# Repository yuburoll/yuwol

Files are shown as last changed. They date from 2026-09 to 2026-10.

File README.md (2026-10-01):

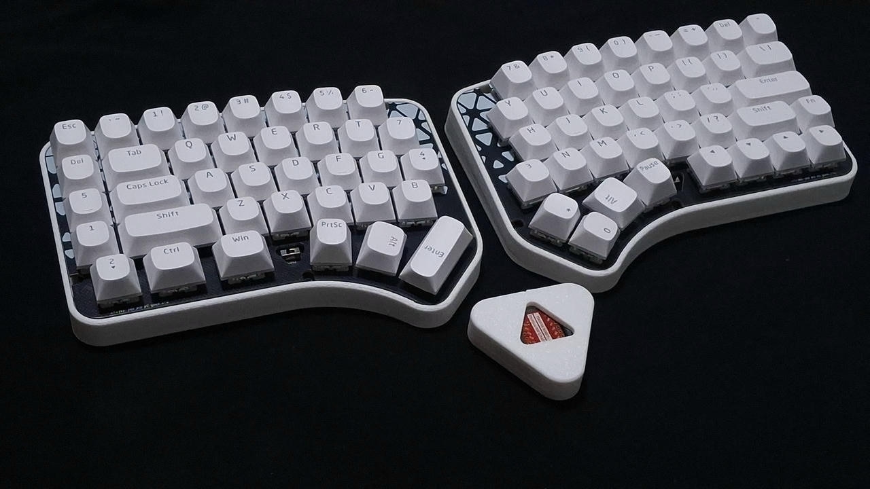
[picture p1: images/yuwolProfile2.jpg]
yuwol


# yuwol
row staggered 60% hotswappable keyboard with reversible PCB, little ergo boost of [ilwol](https://github.com/yuburoll/ilwol)

The name yuwol is June in Korean.

This keyboard has additional Y/H/B keys which positioned between keyboards, and auxilary row at left outside. You may put the keycaps from numpad.

This keyboard has hotswap-only PCB.

yuwol can change layout to followings:

- Split left shift, to ISO shaped one.(2.25u to 1.25u/1u)

- Split right shift, to HHKB inspired shape.(2.75u to 1.75u/1u)

- Split outside thumb keys(2u to 1u/1u)

- Split backspace(2u to 1u/1u)

- Can use stepped caps lock

## Preparation

common:

- 2x yuwol PCB Boards, provided from the repo

- 1x printed case sets, 2 parts total, provided from the repo

- 1x 1.5-1.6T keyboard plate sets, 2 parts total, provided from the repo

- 80x diodes, normally 1N4148

- 84x Kailh hotswap sockets (or compatibles)

- 2x 4x4x1.5mm surface mount tact switches (optional, for dev boards without reset button)

- 1-6x PCB Mounted 2u Keyboard Stabilizers, normally 6

- 73-78x MX Keyswitches, normally 73

- 8x 10mm bumpon stickers

- A set of Keycaps, Full-size layout, ANSI preferred.

for wired build:

- 2x pro micro form factor dev board

- 2x USB-C 6 pin jack, top mount

- 1x USB-C data cable

- 10x M2x6 screws / or M2x3x3 heat inserts and M2x6 bolts

for wireless build:

- 2x pro micro form factor dev board, with wireless chipset

- 2x 523450 battery, with molex picoblade 1.25mm pitch male, 2pin

- 2x molex picoblade 1.25mm pitch female, 2pin

- 2x SS-12D00 switches

- 2x battery cover, provided from the repo

- 14x M2x6 screws / or M2x3x3 heat inserts and M2x6 bolts

dongle:

- 1x pro micro form factor dev board, with wireless chipset

- 1x printed dongle case sets, 2 parts total, provided from the repo

- 2x M2x6 screws / or M2x3x3 heat inserts and M2x6 bolts

- 3x 10mm bumpon stickers

## Differences between case variations

- Screw: 1.5 pi mounting holes for screws

- Insert: 3 pi mounting holes for heat inserts

## Build Guides and Miscellaneous

[yuwol Build Guide](docs/buildGuide.md)

there's some notices before the build:

- You may solder all hotswaps before soldering the dev board.

- Assemble dev board with 2.5mm height pin headers on back side, assume that components side are faced up.

- Jump a jumper when it is left hand board.

[Additional Tenting Stand](https://github.com/yuburoll/yubuGadgets/tree/main/phalilwolTentingStand)

## Licenses

all codes follow MIT license.

all designs and the hardware board follow CC BY-SA 4.0 license.

Markdown documents and photos in docs/images folder are copyrighted, all rights reserved. You can use it for [fair use](https://www.copyright.gov/fair-use/).

If you want to make a commercial product, it would be appreciated if you sponsor some bucks for me.

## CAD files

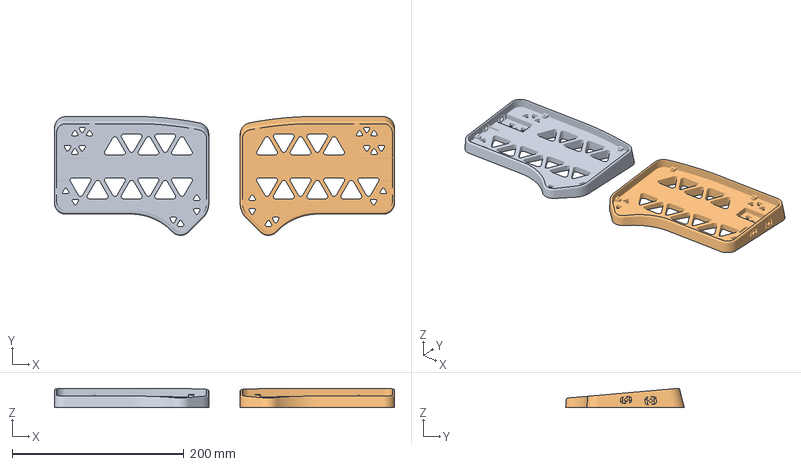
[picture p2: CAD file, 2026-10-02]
case/3mf/yuwolWiredInsert.3mf
395.5 x 138.2 x 22.5 mm
yuwolCaseWiredInsertBridgedL.stl
yuwolCaseWiredInsertBridgedR.stl

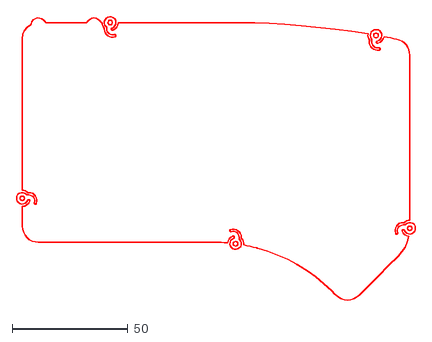
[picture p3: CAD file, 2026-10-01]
case/dxf/yuwolPCB.dxf
172.9 x 123.3

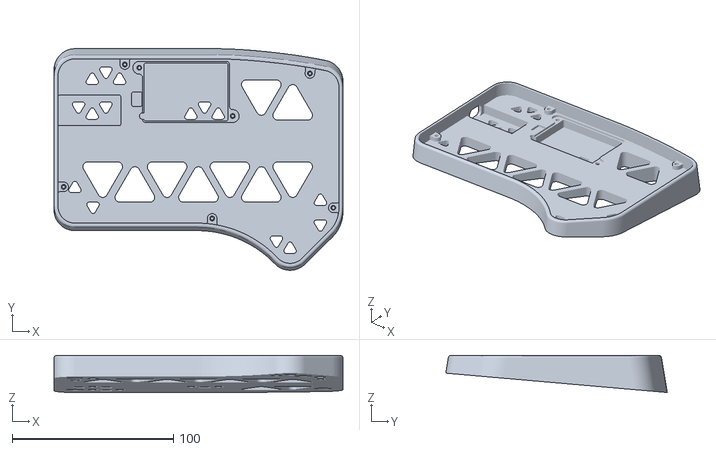
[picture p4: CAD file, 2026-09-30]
case/stl/insert/yuwolCaseWirelessInsertL.stl
179.5 x 137.6 x 23.0

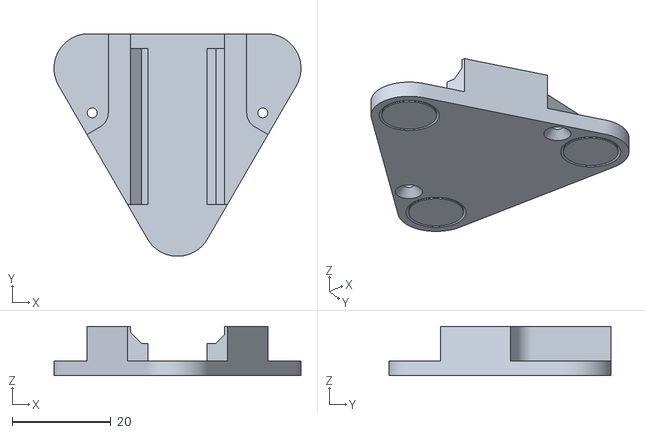
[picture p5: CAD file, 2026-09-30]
case/stl/yuwolDongleBottomBridged.stl
49.9 x 45.0 x 10.0

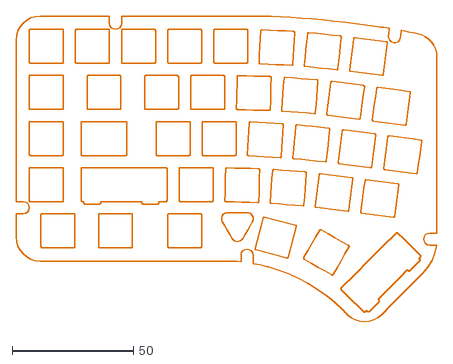
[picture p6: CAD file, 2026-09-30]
housing/dxf/yuwolPlateLeft.dxf
173.5 x 127.0

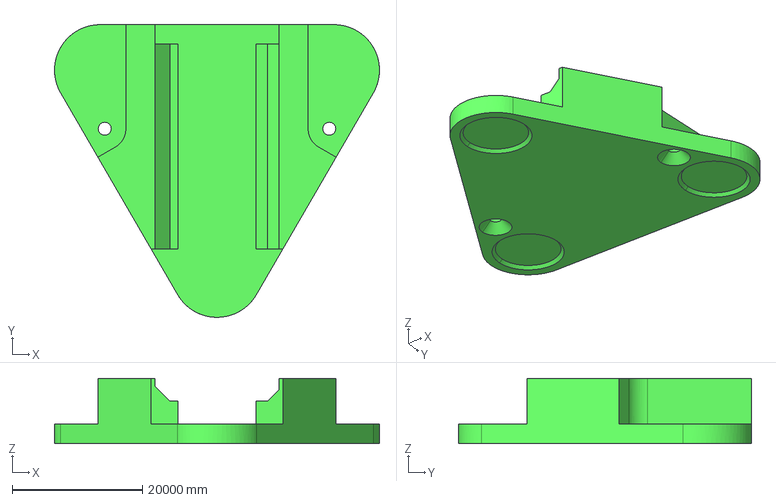
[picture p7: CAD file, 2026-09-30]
housing/step/yuwolDongleBottom.stp
49944.0 x 44986.3 x 10000.0 mm

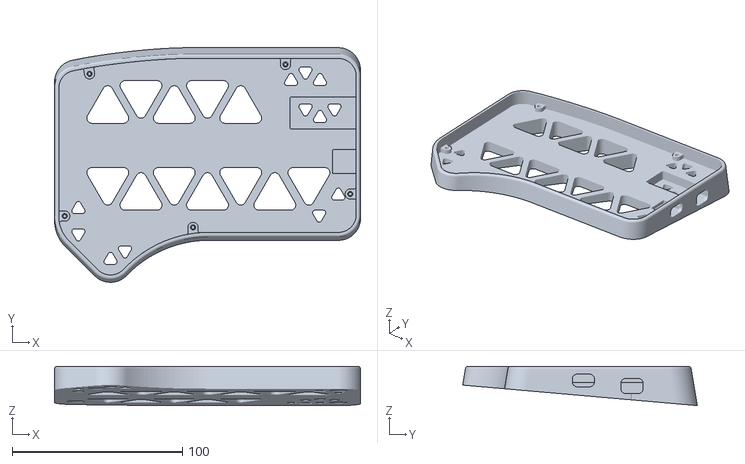
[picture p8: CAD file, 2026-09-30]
housing/stl/insert/yuwolCaseWiredInsertR.stl
179.5 x 137.6 x 23.0

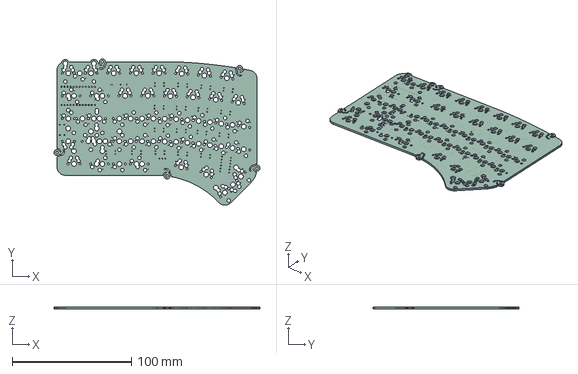
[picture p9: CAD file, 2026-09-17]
kicad/yuwolPCB.step
172.5 x 122.5 x 1.51 mm

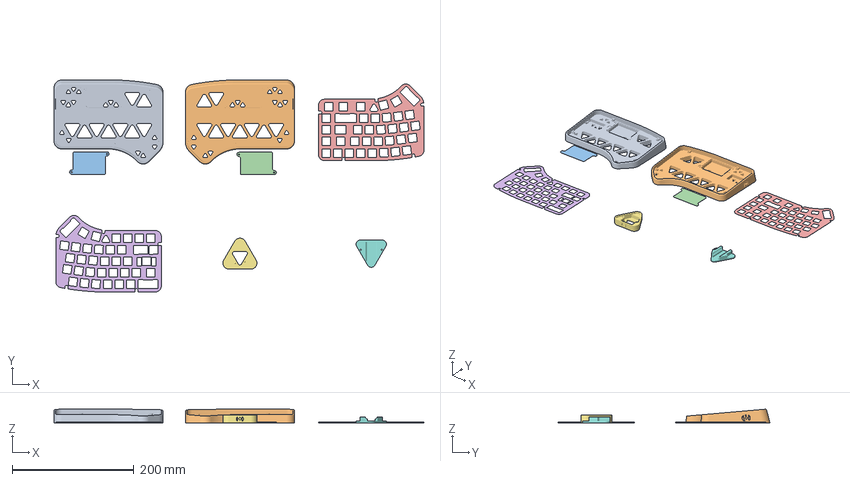
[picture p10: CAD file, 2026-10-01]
housing/3mf/yuwolWirelessInsert.3mf
608.5 x 348.5 x 22.5 mm
yuwolCaseWirelessInsertBridgedL.stl
yuwolCaseWirelessInsertBridgedR.stl
yuwolCaseWirelessBatteryCoverL.stl
yuwolCaseWirelessBatteryCoverR.stl
yuwolPlateL.stl
yuwolPlateR.stl
yuwolDongleTopInsertBridged.stl
yuwolDongleBottomBridged.stl

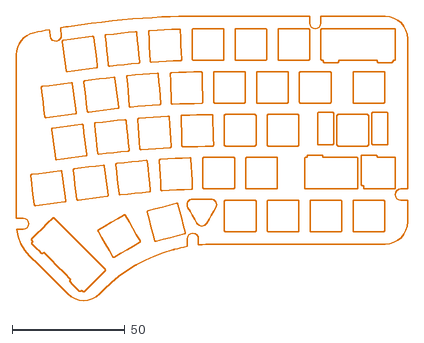
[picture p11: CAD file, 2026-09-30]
housing/dxf/yuwolPlateRight.dxf
173.5 x 127.0

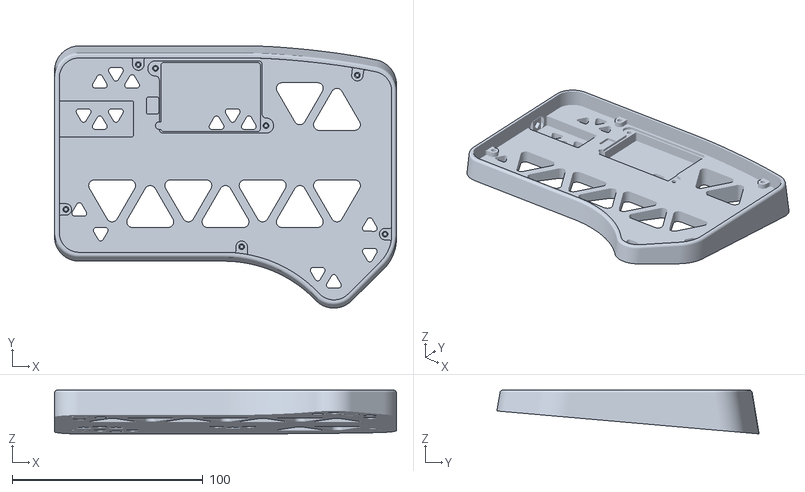
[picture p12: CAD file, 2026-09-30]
case/stl/insert/yuwolCaseWirelessInsertBridgedL.stl
179.5 x 137.6 x 23.0

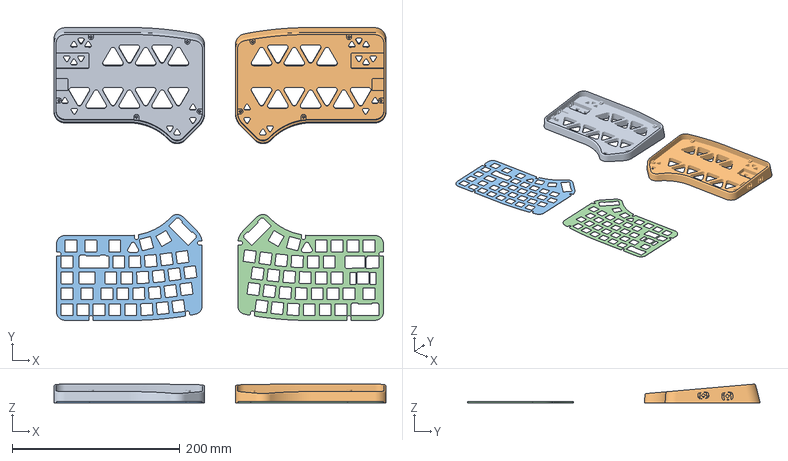
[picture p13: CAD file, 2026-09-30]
housing/3mf/yuwolWiredInsert.3mf
395.5 x 348.5 x 22.5 mm
yuwolCaseWiredInsertBridgedL.stl
yuwolCaseWiredInsertBridgedR.stl
yuwolPlateL.stl
yuwolPlateR.stl

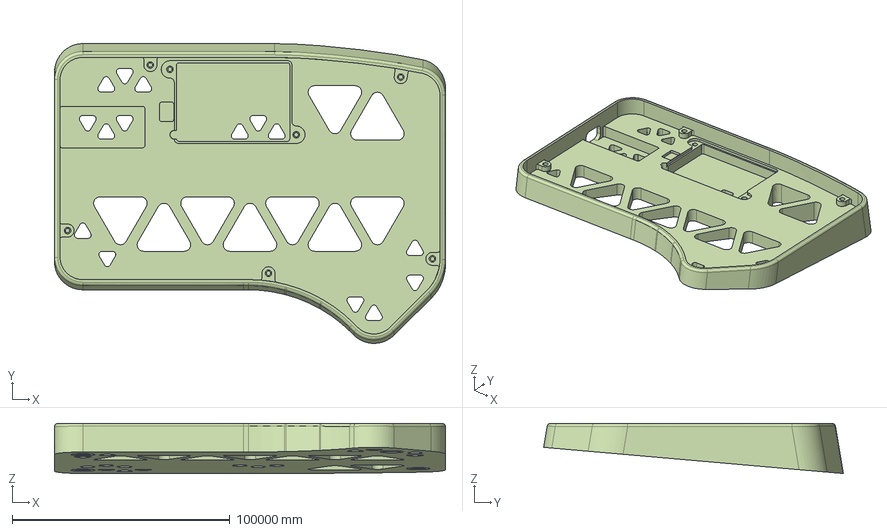
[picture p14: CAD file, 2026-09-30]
housing/step/yuwolCaseWirelessInsertL.stp
179500.0 x 137628.1 x 23009.1 mm

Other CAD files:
case/stl/insert/yuwolCaseWiredInsertBridgedR.stl
housing/stl/insert/yuwolCaseWiredInsertL.stl
Case/dxf/yuwolLeftPlate.dxf
Case/dxf/yuwolRightPlate.dxf
Case/raw/yuwol.3dm
case/3mf/yuwolPlates.3mf
case/3mf/yuwolWiredScrew.3mf
case/3mf/yuwolWirelessInsert.3mf
case/3mf/yuwolWirelessScrew.3mf
case/dxf/yuwolPattern.dxf
case/dxf/yuwolPositioning.dxf
case/dxf/yuwolTriangle.dxf
case/raw/yuwolDongle.3dm
case/raw/yuwolPattern.3dm
case/step/yuwolCaseWiredInsertL.stp
case/step/yuwolCaseWiredInsertR.stp
case/step/yuwolCaseWiredScrewL.stp
case/step/yuwolCaseWiredScrewR.stp
case/step/yuwolCaseWirelessBatteryCoverL.stp
case/step/yuwolCaseWirelessBatteryCoverR.stp
case/step/yuwolCaseWirelessInsertR.stp
case/step/yuwolCaseWirelessScrewL.stp
case/step/yuwolCaseWirelessScrewR.stp
case/step/yuwolDongleTopInsert.stp
case/step/yuwolDongleTopScrew.stp
case/step/yuwolPlateL.stp
case/step/yuwolPlateR.stp
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

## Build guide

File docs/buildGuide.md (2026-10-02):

# Build Guide
This is the build guide for yuwol.

This build guide contains photos of the prototype version.

Note: The PCBs of the photo above are prototype. There are a little difference between release; two outside screw hole leafs are mirrored because of rigidity. 

This document was translated by generative AI, so some text may be misleading.

### Additional Resources
[**Soldering Tips**](solderingTip.md)

[**Dongle Build Guide**](dongleBuild.md)

## PCB Preparation
Prepare two PCBs for the yuwol. Since these are reversible PCBs, be careful to place components on different sides for each board.

The side where components will be placed is treated as the back, and the side without components is treated as the front. **All components go on the back side, except battery switches for wireless. Please be careful when soldering.**

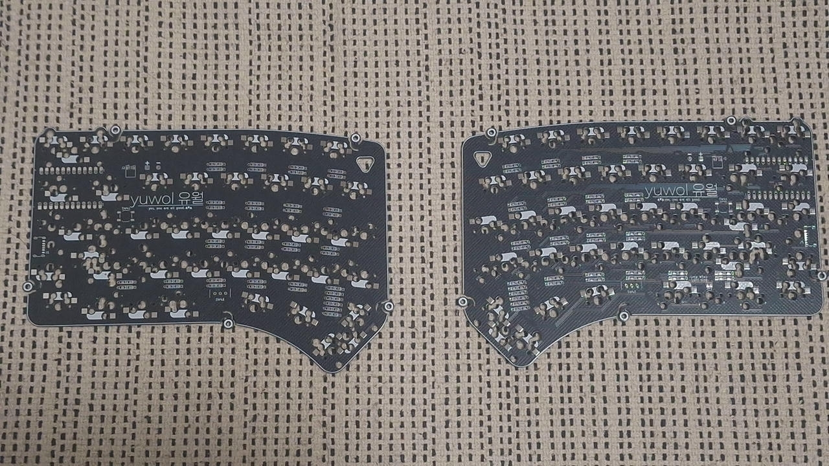
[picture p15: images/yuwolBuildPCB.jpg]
yuwolBuildPCB


## Soldering the Diodes
Solder the diodes. The photos show SMD diodes being used, but THT diodes can also be used.

When using SMD diodes, first apply a solder blob to one side of the pad with a soldering iron, as shown in the following photos.

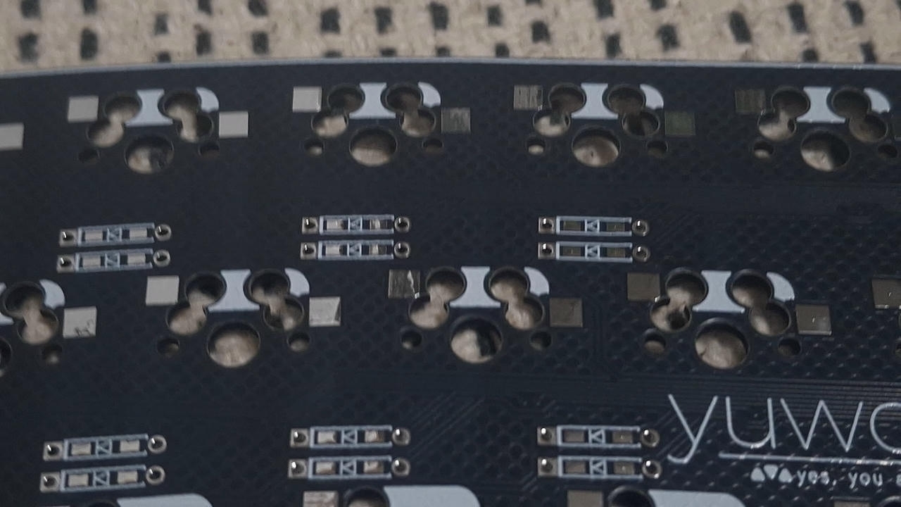
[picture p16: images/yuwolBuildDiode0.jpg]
yuwolBuildDiode0

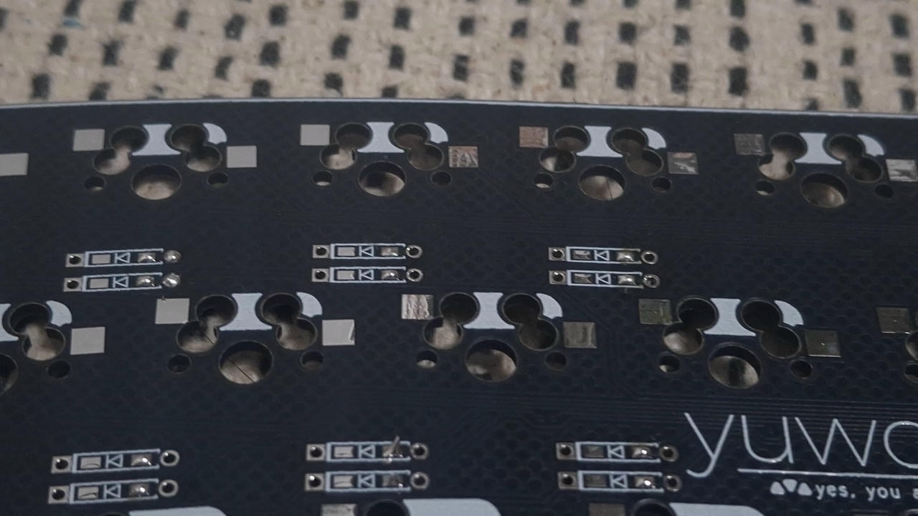
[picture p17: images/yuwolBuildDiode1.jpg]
yuwolBuildDiode1


Reheat the solder blob with the iron to melt it, align the diode in the correct orientation and place it in position, then remove the iron.

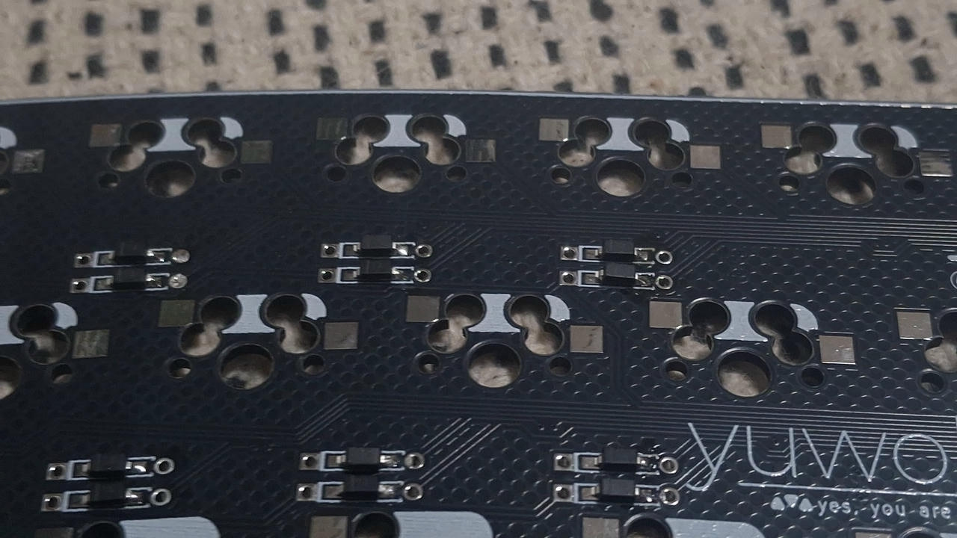
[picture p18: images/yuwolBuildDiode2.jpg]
yuwolBuildDiode2


Once it is seated properly, solder the opposite leg.

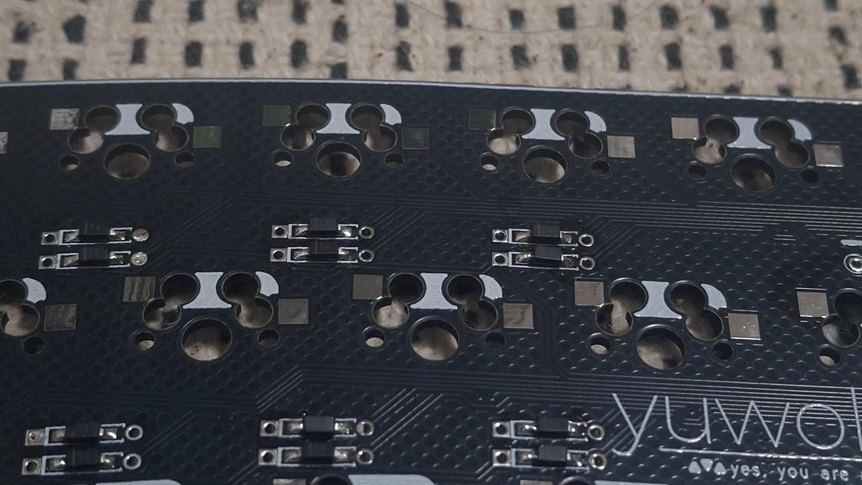
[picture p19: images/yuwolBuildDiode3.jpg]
yuwolBuildDiode3


## Soldering the Hot-swap Sockets
Solder the hot-swap sockets. The process is largely the same as soldering the diodes.

As before, apply a solder blob to one side of the pad, reheat the blob to melt it, place the component and hold it in position, remove the iron, then solder the opposite leg.

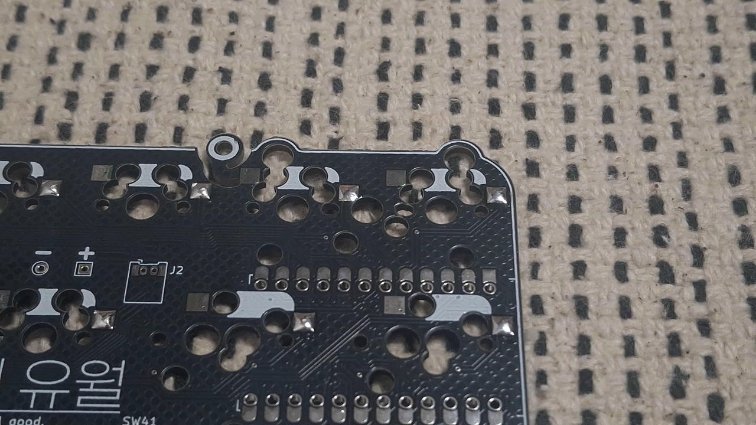
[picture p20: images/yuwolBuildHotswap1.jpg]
yuwolBuildSocket1

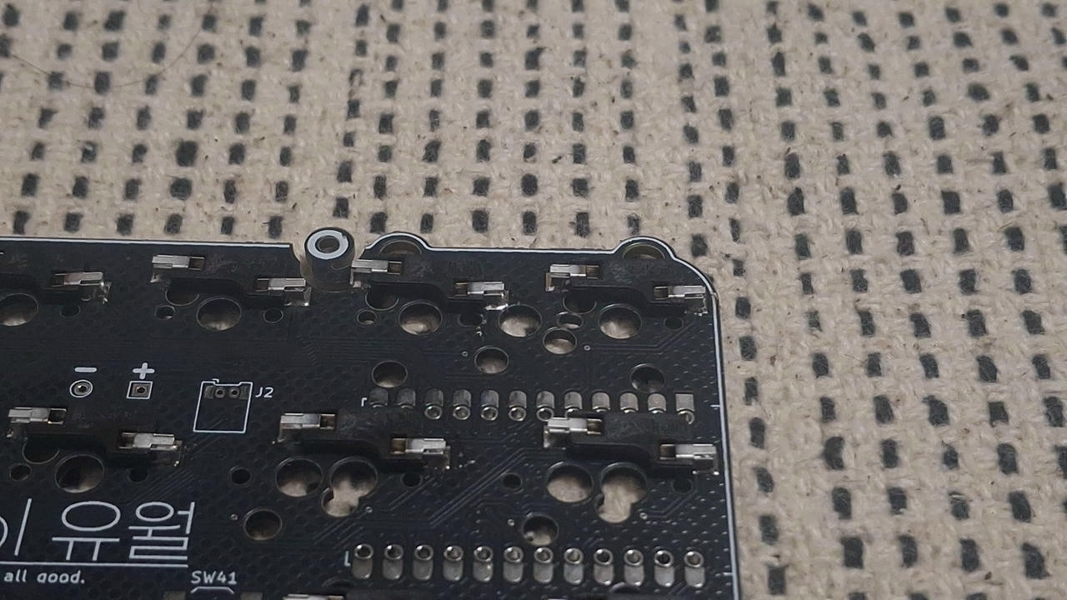
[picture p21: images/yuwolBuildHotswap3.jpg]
yuwolBuildSocket3


## (Optional) Soldering the Reset Switch
As with the diodes and hot-swap sockets, apply a solder blob to one side of the pad, reheat the blob to melt it, place the component and hold it in position, remove the iron, then solder the opposite legs. You may solder all four legs.

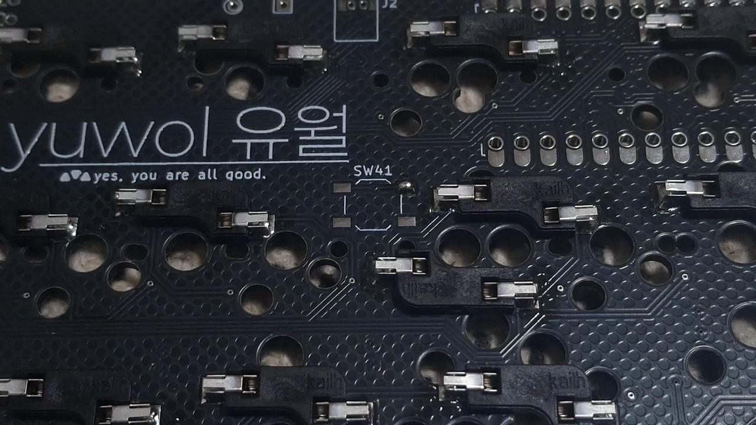
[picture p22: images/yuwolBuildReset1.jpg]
yuwolBuildReset1

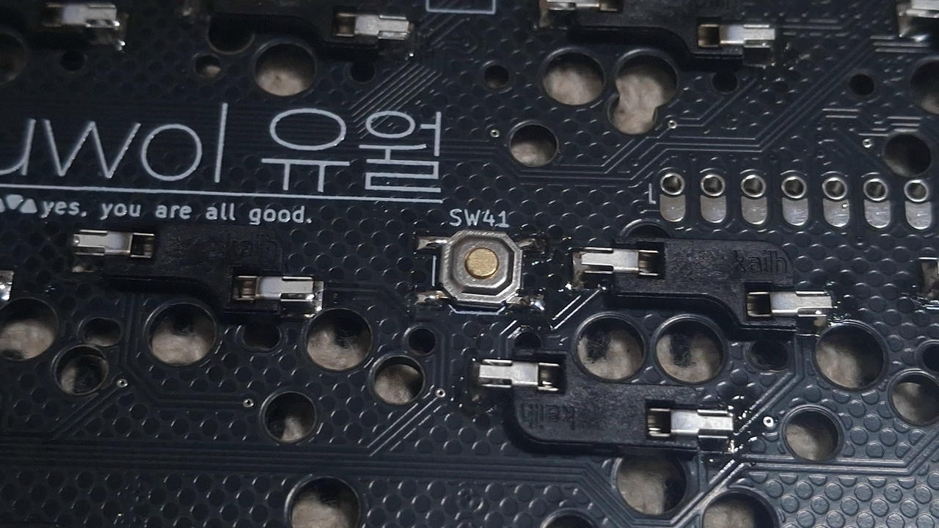
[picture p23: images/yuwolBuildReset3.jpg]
yuwolBuildReset3


## (Wired) Soldering the USB-C Jack and the Jumper
Refer to the following photos to identify where the USB-C jack will be placed. The jack will be placed on the back side.

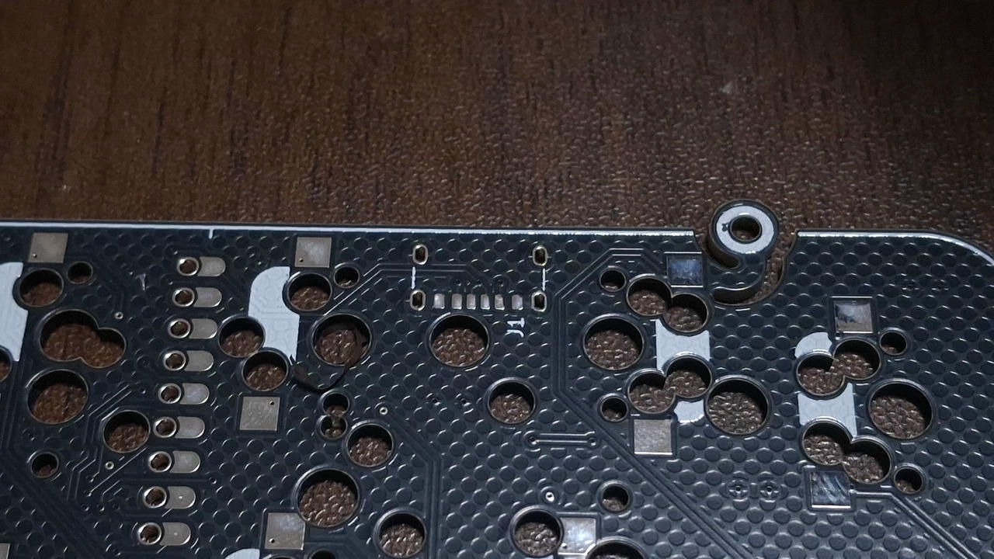
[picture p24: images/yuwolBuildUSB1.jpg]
yuwolBuildUSB1


Solder the USB-C jack on the back side. Apply solder blobs to the pads on the back side and heat them. Then, solder the remaining legs.

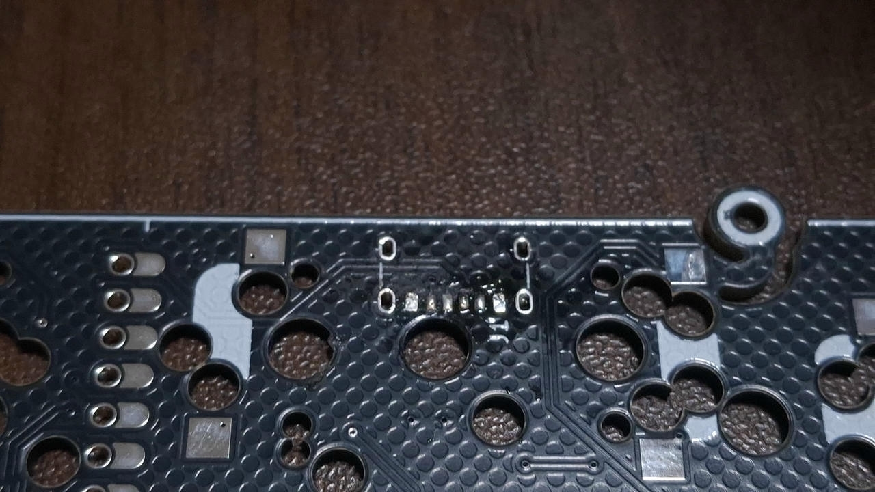
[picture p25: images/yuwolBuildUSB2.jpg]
yuwolBuildUSB2

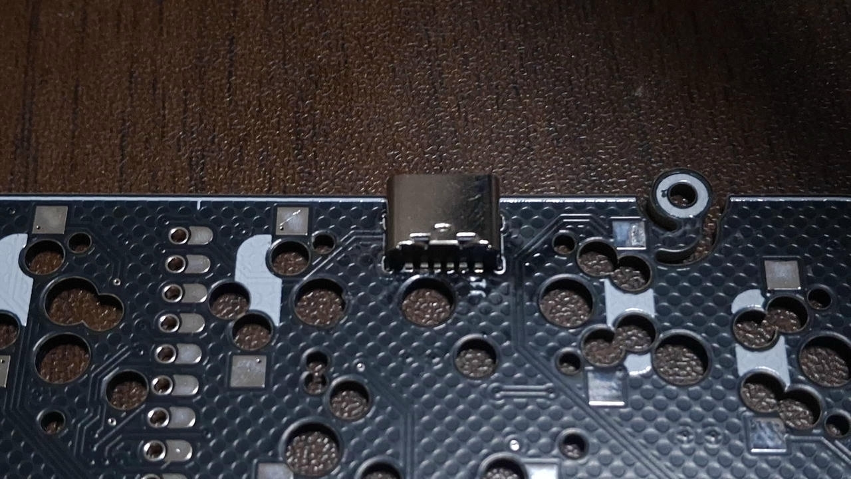
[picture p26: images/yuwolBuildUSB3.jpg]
yuwolBuildUSB3


On the left PCB, bridge the jumpers located at the bottom. Apply enough solder so that a blob forms on top.

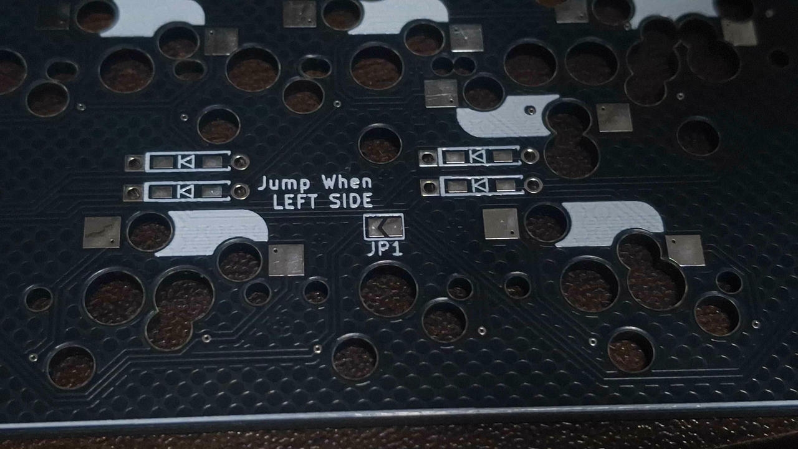
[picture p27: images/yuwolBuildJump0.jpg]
yuwolBuildJump0


## (Wireless) Soldering the Battery Switch and the Battery Jack
Solder the battery switch. The battery switch goes on the front side, so solder it from the back side.

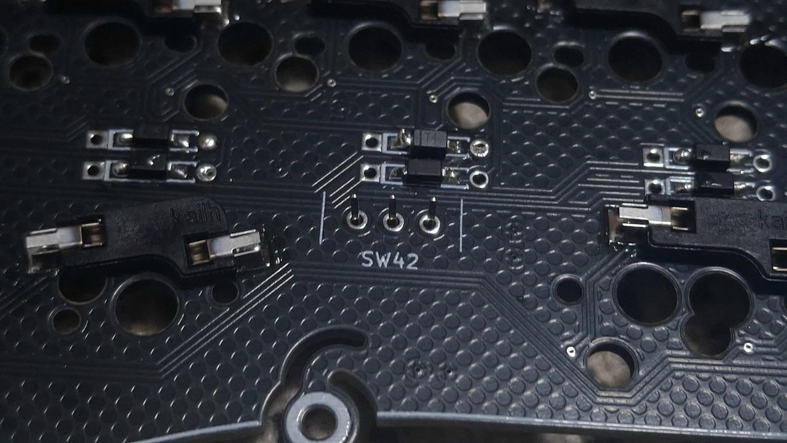
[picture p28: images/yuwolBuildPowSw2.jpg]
yuwolBuildPowSw2

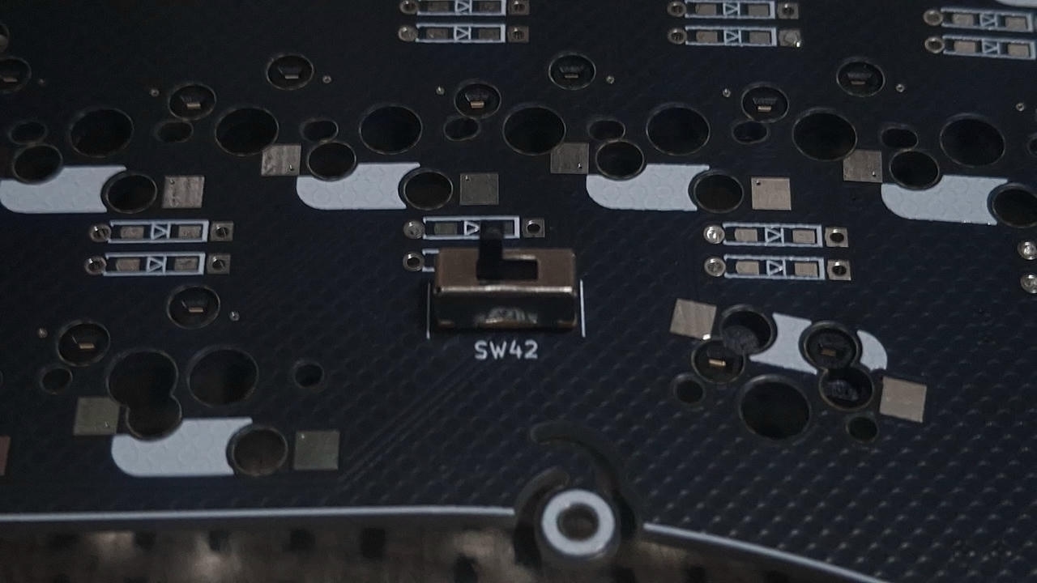
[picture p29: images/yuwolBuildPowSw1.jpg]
yuwolBuildPowSw1


Insert the 2-pin Molex jack on the back side and solder it from the front side. Bridge the pins to the adjacent pads as if soldering jumpers.

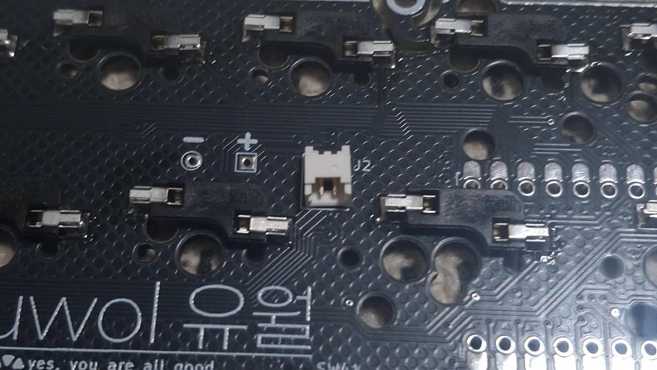
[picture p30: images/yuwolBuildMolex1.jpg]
yuwolBuildMolex1

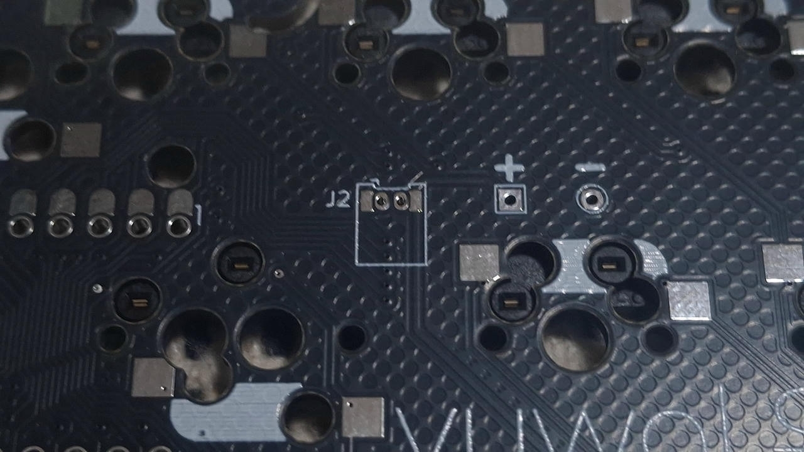
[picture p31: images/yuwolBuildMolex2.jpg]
yuwolBuildMolex2

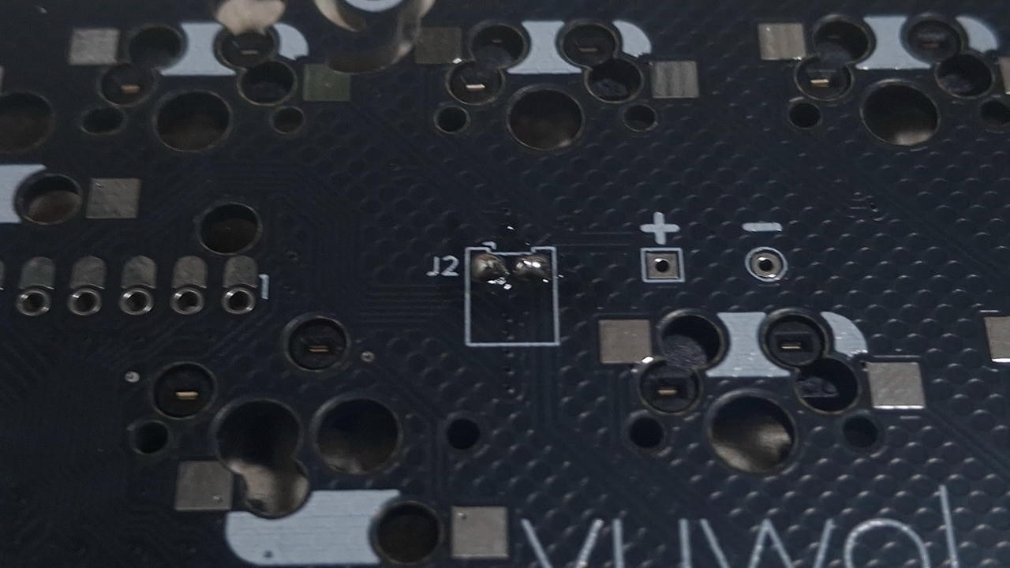
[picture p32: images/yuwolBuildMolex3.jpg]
yuwolBuildMolex3


## Soldering the Dev Board
First, check the header pins on the provided Pro Micro dev board. The outermost row of header pins past 5V is not needed, so trim them off.

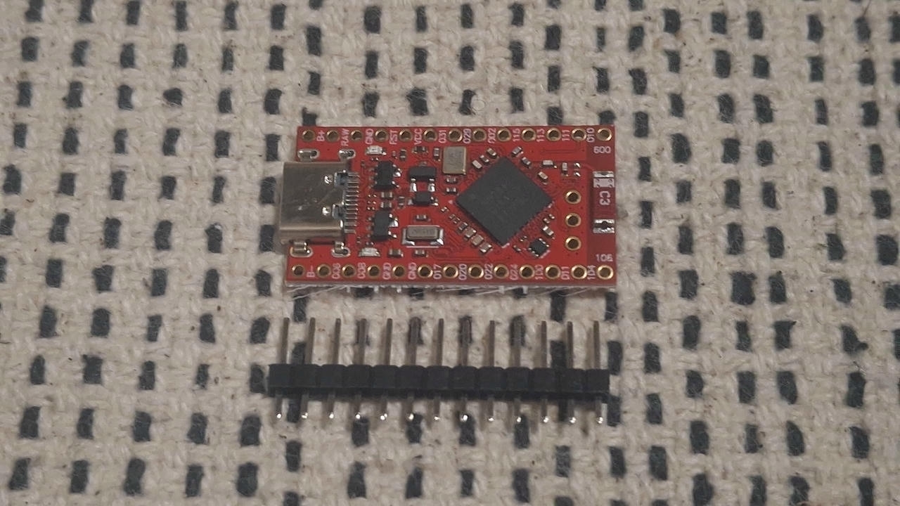
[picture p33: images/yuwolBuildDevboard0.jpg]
yuwolBuildDevboard0

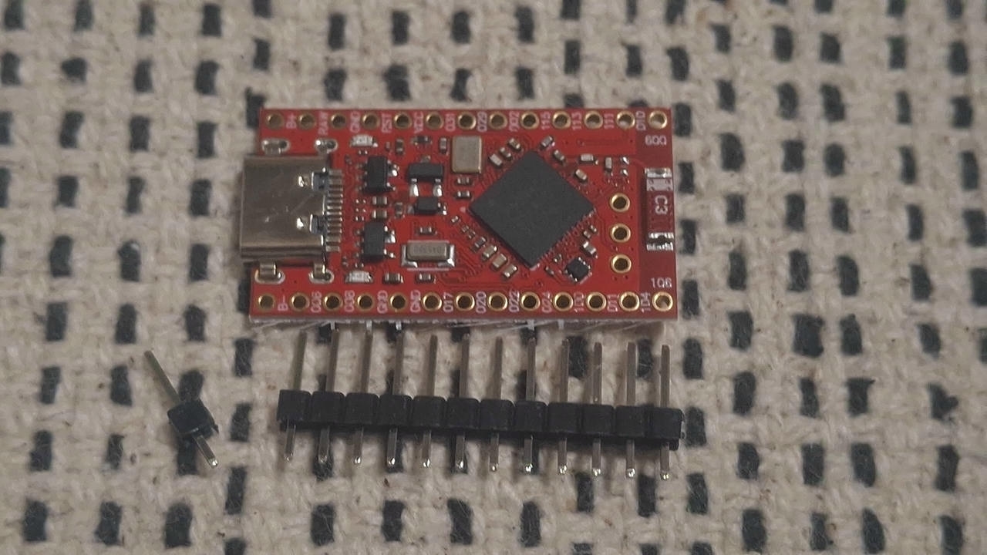
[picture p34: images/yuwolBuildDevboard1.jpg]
yuwolBuildDevboard1


Insert the header pins starting from 5V, align them, and solder the dev board. When soldering, make sure the components face upward as shown in the photo.

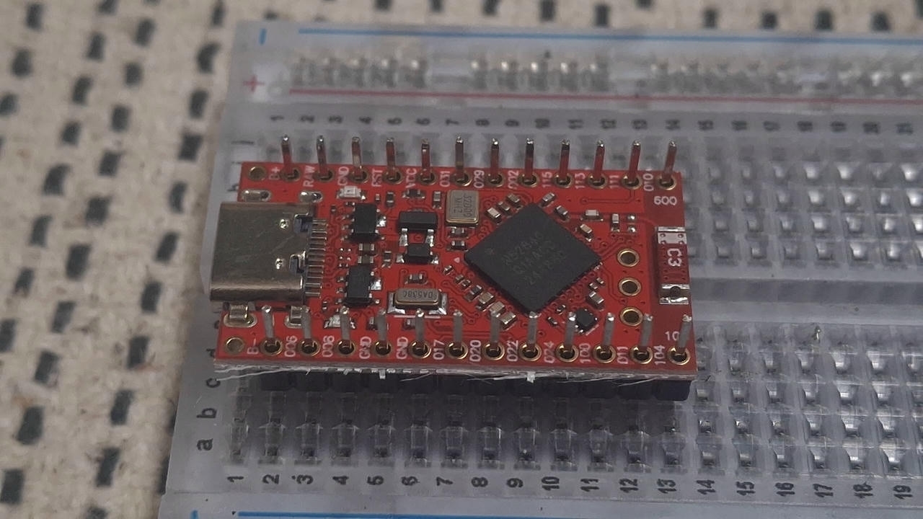
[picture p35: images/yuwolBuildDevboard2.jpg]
yuwolBuildDevboard2

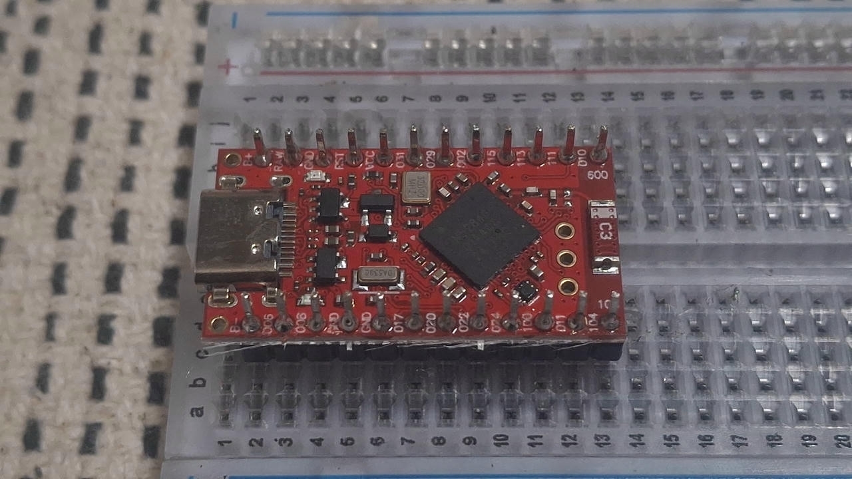
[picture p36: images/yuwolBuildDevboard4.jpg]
yuwolBuildDevboard4


Place the dev board with the soldered header pins on top of the already-soldered hot-swap sockets, and tack-solder the four corner points in advance.

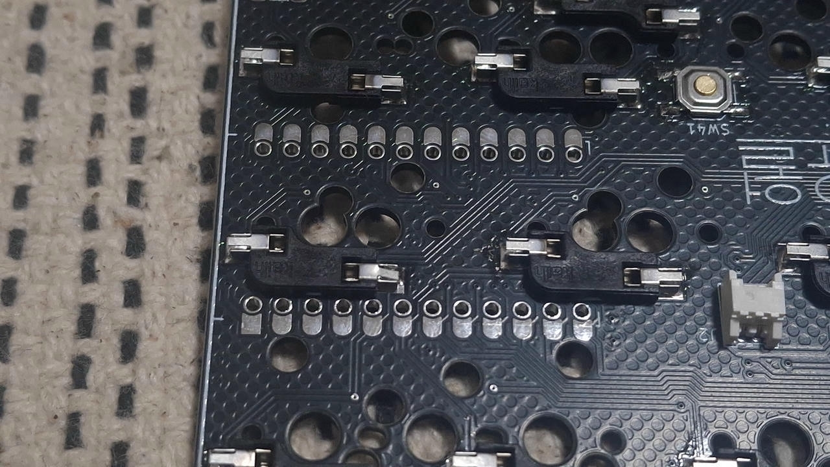
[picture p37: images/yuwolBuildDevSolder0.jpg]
yuwolBuildDevSolder0

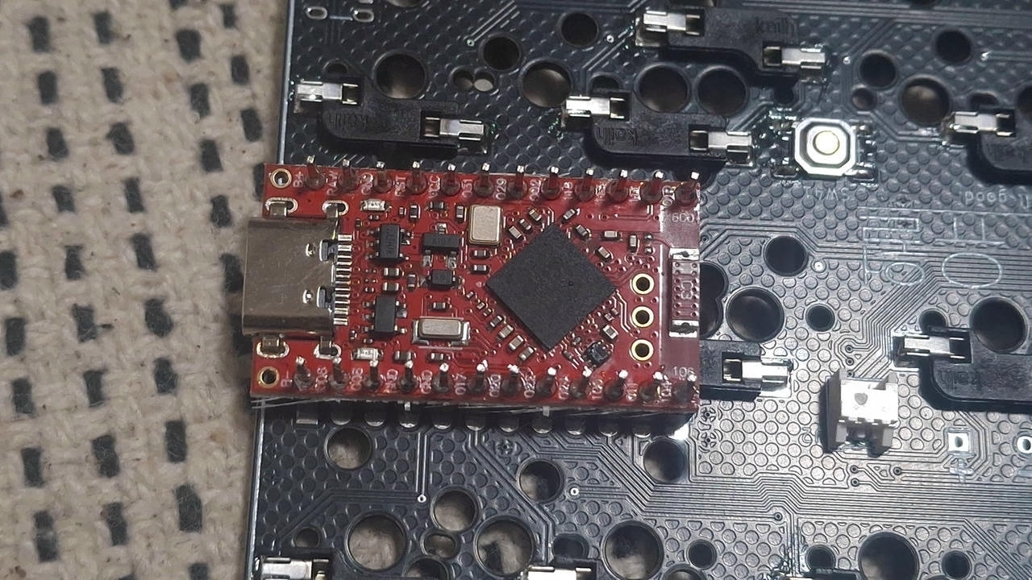
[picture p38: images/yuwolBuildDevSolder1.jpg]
yuwolBuildDevSolder1

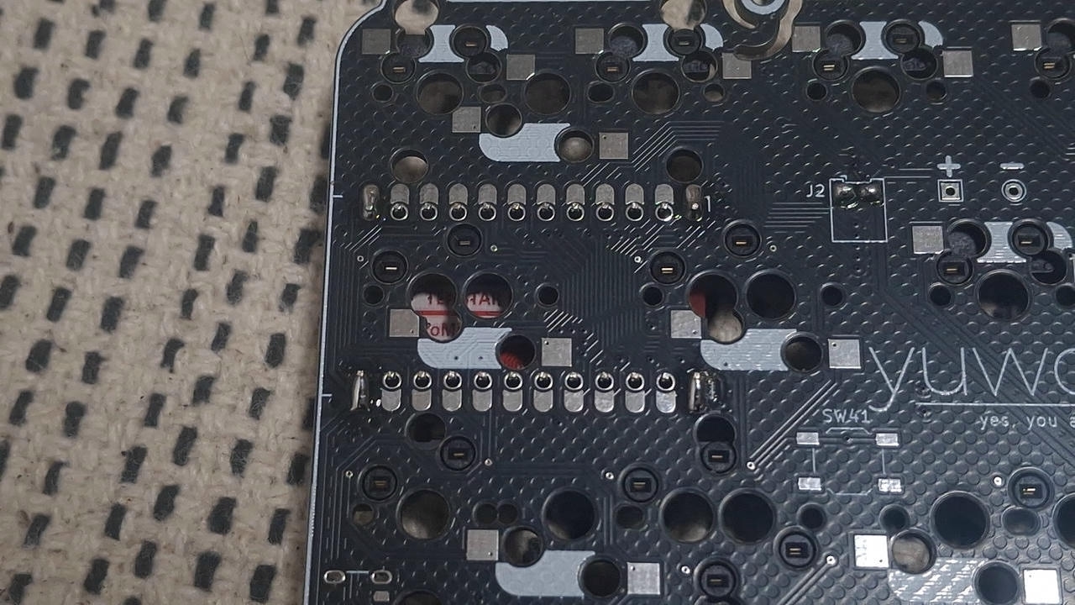
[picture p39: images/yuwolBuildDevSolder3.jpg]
yuwolBuildDevSolder3


While heating the pre-soldered corner points, press down the dev board firmly to ensure a tight fit.

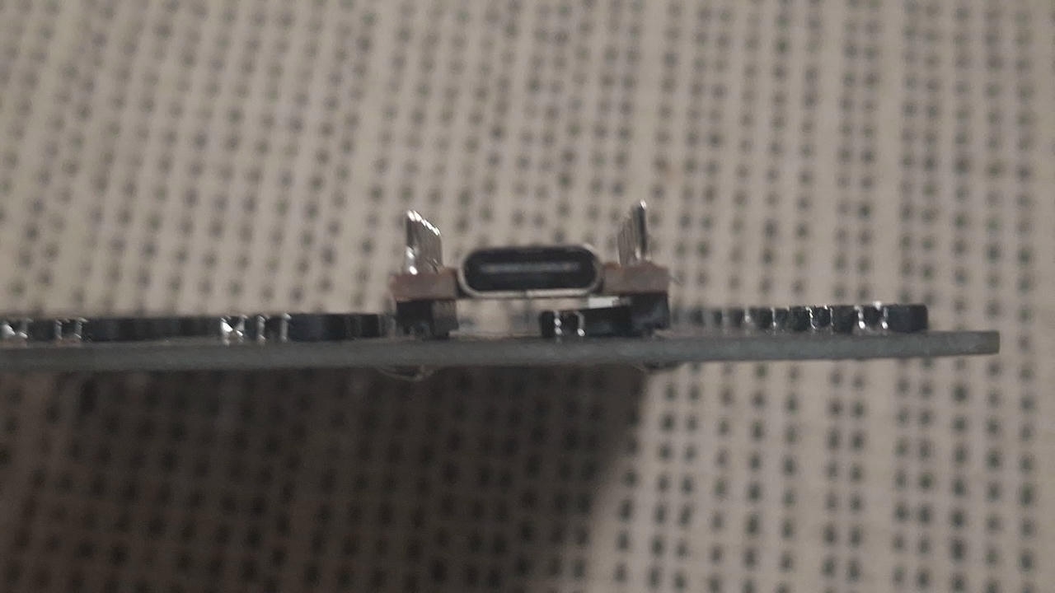
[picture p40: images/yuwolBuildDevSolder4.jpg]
yuwolBuildDevSolder4


Bridge the header pins to the adjacent pads as if soldering jumpers. Since a large amount of solder is used, there is a risk of bridging from flux residue, so be sure to clean the area with alcohol after soldering.

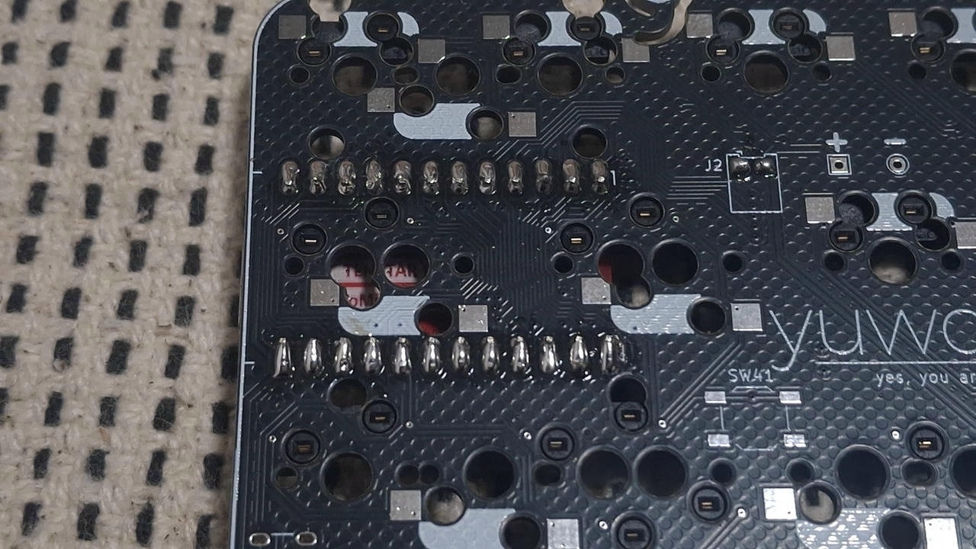
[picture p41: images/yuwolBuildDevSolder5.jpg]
yuwolBuildDevSolder5


## Check PCB and flash firmware before Assembly
One side of a finished wireless PCB looks like the following image.

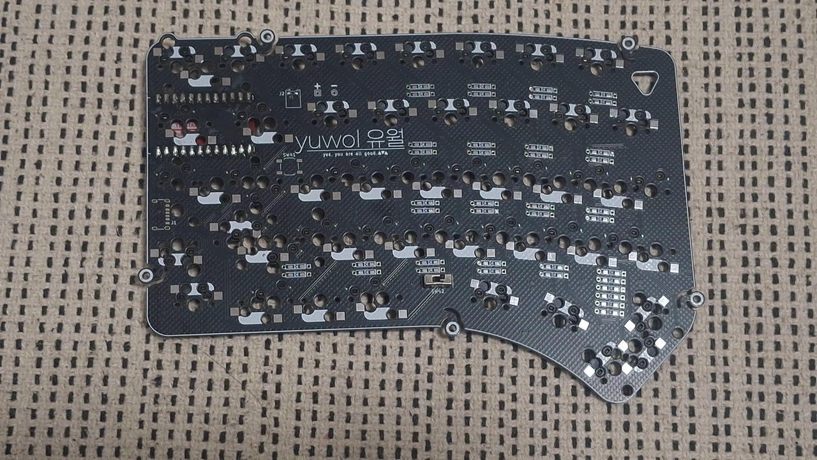
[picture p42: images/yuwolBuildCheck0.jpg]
yuwolBuildCheck0

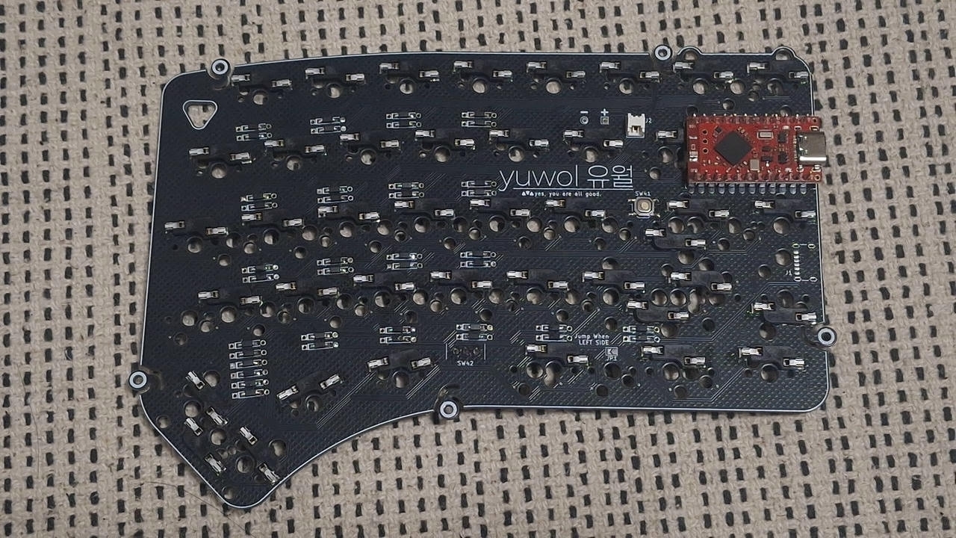
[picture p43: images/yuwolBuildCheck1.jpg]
yuwolBuildCheck1


If you're a keyboard enthusiast, I'd recommend installing stabilizers at keycap positions 2u or larger, as shown in the following photo.

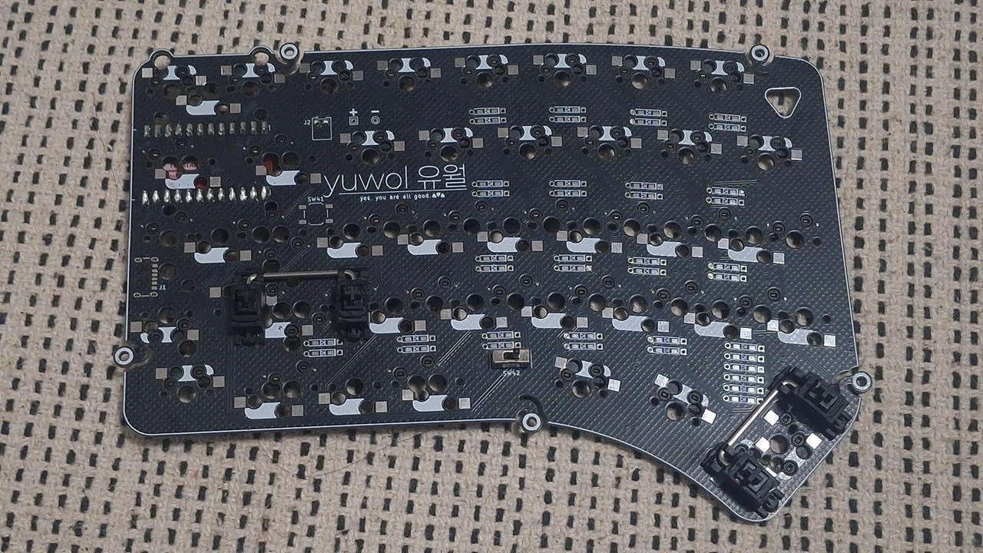
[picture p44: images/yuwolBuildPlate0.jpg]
yuwolBuildPlate0


Also, please flash the firmware before assembling the case.

For the RP2040 Pro Micro, hold down the Boot button on the development board while connecting the USB, then drop the .uf2 file onto the removable disk that appears.

For the ATmega32U4 Pro Micro, load the firmware .hex in your flashing tool (e.g., QMK Toolbox). Then, with the USB connected, briefly short RST and GND with a conductor, or solder a 4x4x1.5mm tactile switch to those pads and press it. The Caterina bootloader will activate and the tool will flash the firmware.

For the nice!nano and its clones, with the USB connected, briefly short RST and GND with a conductor, or solder a 4x4x1.5mm tactile switch to those pads and press it twice. Then drop the .uf2 file onto the removable disk that appears.

## Plate Assembly
First, insert the switches into the top and bottom of the plate in the correct orientation, then mount the PCB onto them.

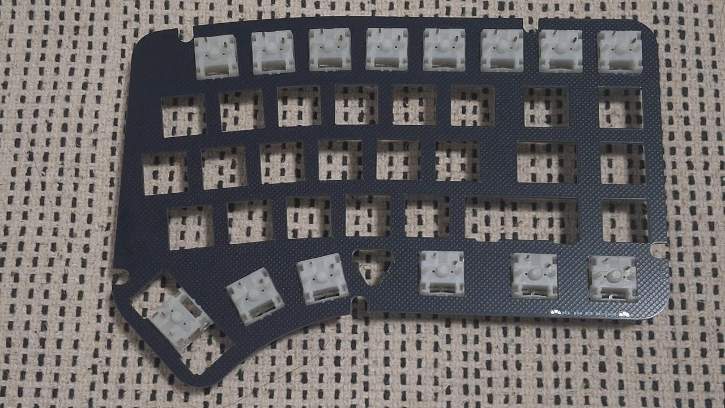
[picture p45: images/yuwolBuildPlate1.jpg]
yuwolBuildPlate1

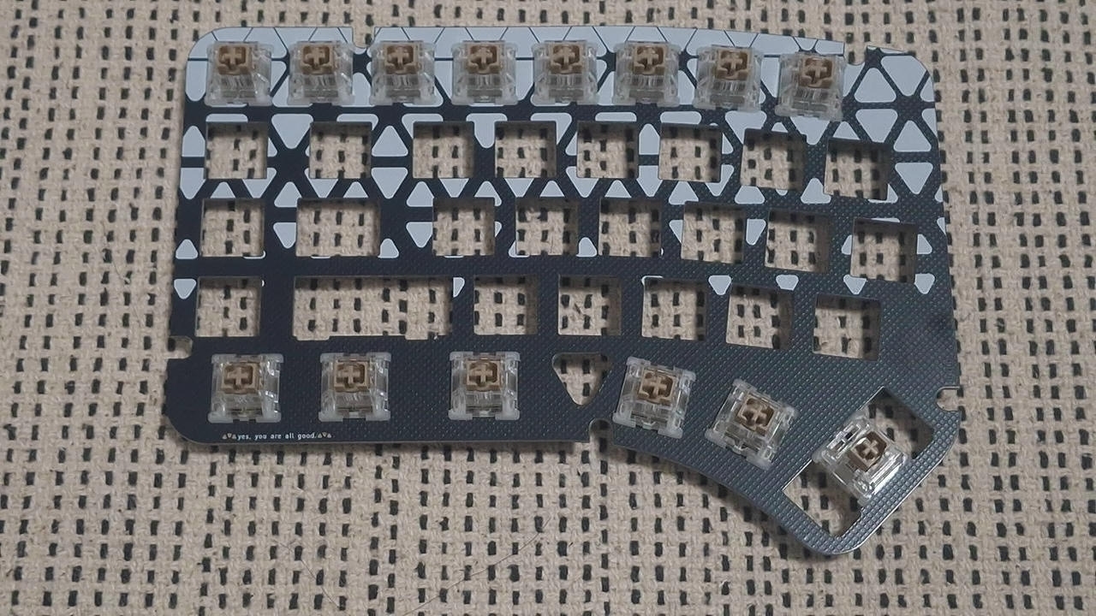
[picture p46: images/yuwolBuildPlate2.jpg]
yuwolBuildPlate2

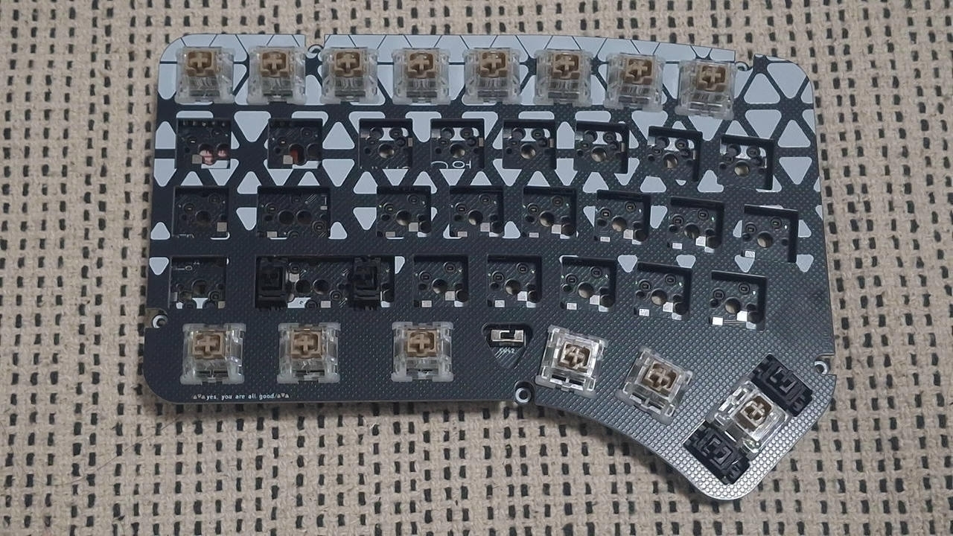
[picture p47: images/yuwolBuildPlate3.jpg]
yuwolBuildPlate3


After that, put the remaining switches on the plate assembly.

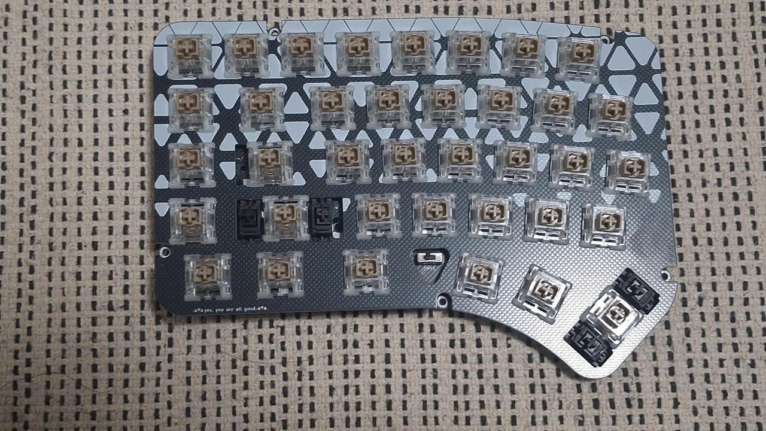
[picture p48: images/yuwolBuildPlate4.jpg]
yuwolBuildPlate4


## (Optional) Add Heat Inserts
First, place the heat inserts over the holes, then push them in with the soldering iron until they are properly seated.

Do not push too hard, or the inserts will sit too deep.

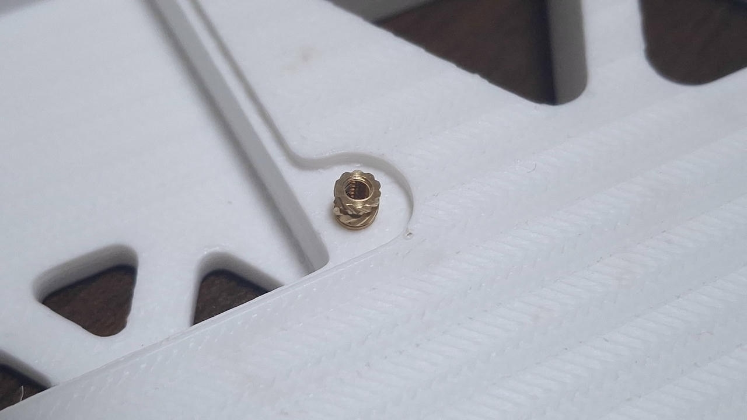
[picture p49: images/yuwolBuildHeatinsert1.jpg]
yuwolBuildHeatinsert1

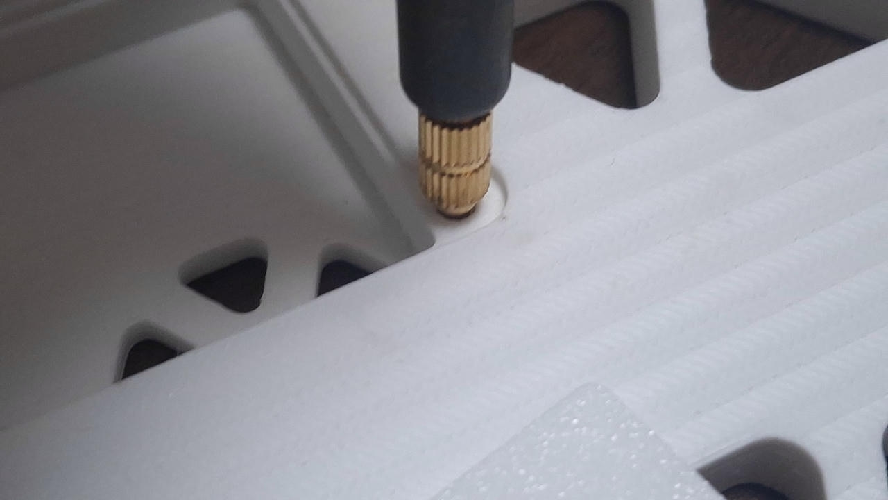
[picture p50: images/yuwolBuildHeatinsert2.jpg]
yuwolBuildHeatinsert2

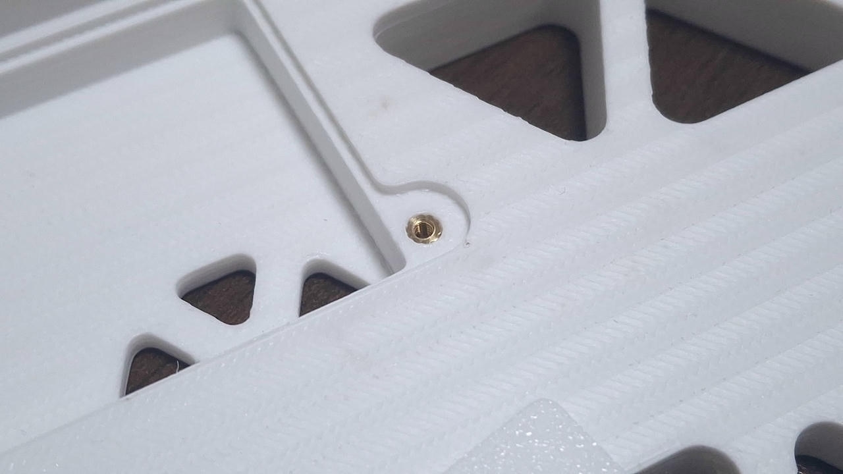
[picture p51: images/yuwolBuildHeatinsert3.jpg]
yuwolBuildHeatinsert3


## (Wireless) Battery Cover Assembly
Put the battery in the hole of the case, and put the battery cover on it.

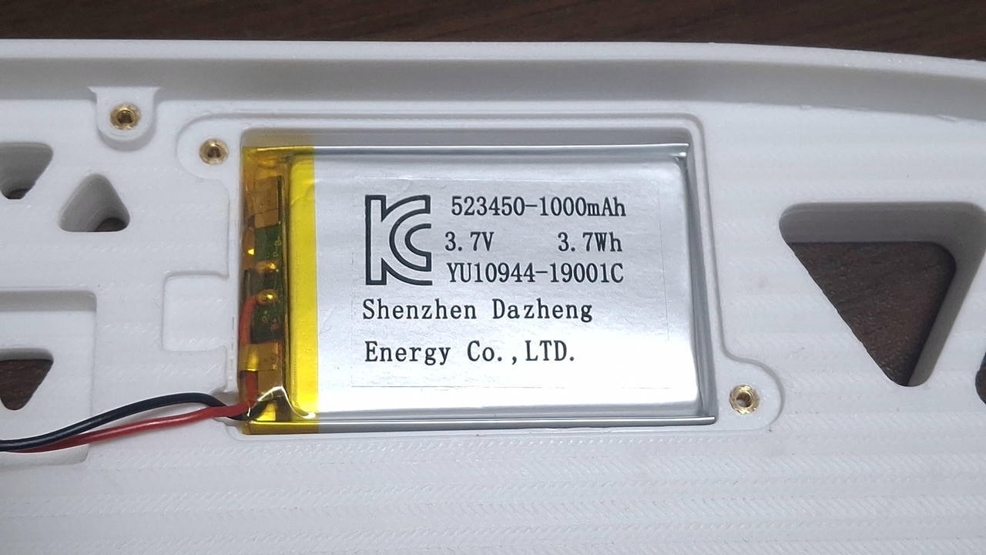
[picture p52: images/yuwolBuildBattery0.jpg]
yuwolBuildBattery0

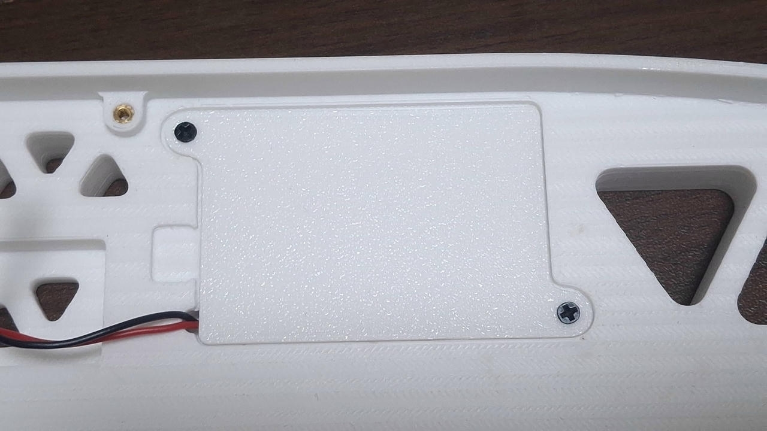
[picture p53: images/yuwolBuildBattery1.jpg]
yuwolBuildBattery1

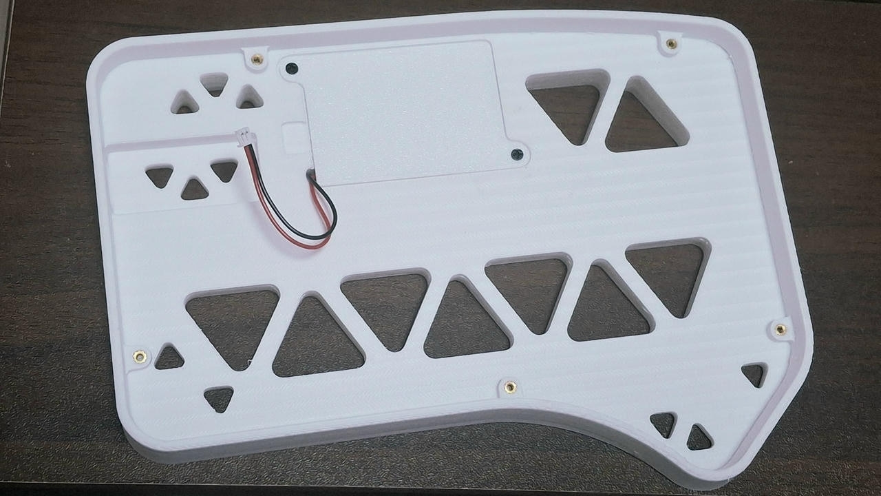
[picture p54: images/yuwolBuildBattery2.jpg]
yuwolBuildBattery2


After that, connect the jack from the PCB and the battery.

yuwolBuildBattery3

## Case Assembly
Place the plate assembly over the case and fasten it with screws at five points per side to complete the build. Also, you may add four bumpons on the bottom of the case.

yuwolBuildCase0
yuwolBuildCase1
yuwolBuildCase2

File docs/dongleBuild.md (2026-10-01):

# Dongle Build Guide
This is a short build guide for yuwol dongle case.

## Preparation
You need a promicro with a wireless chipset, a top case, a bottom case, two screws/bolts, and optionally three bumpons.

yuwolBuildDongle0

## Build
First, flip the top case and look inside.

yuwolBuildDongle1

Inside you can see two asymetric bumps. Place the promicro's gnd pins over the bumps, with the component side up.

yuwolBuildDongle2

Put the bottom case over it carefully and fasten the screws/bolts.

yuwolBuildDongle3

Add the bumpons, and flip it.

yuwolBuildDongle4

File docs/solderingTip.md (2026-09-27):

# Soldering Tips

A collection of soldering advice and tips.

This documents are translated by generative AI, so there can be some misleading texts.

## Supplies

- Soldering iron & stand: A chisel tip is the most convenient to work with. I recommend getting one that can maintain a temperature of at least 400–500°C.

- Solder: Choose between leaded and lead-free solder. Leaded solder is less stressful to work with, but it is not good for your health.

- Solder paste (flux): **The god of soldering.** If your solder joints are not turning out well, frequently wipe and coat the iron tip with paste flux.

- Damp sponge/paper towel, or a tip cleaner (brass wool): Used to wipe residual solder off the iron tip.

- Solder wick or solder sucker: Used to fix bad solder joints. For beginners, solder wick is recommended.

- Flush cutters: Used to clip the legs of THT diodes after soldering.

## Ventilate Your Workspace

The metal fumes from melting solder are a concern, but they are actually quite minimal. The bigger issue is the smoke from the rosin flux inside the solder burning and melting — it is quite harmful and produces a lot of smoke. It is very bad for your health, so ventilate the area, or if ventilation is not possible, make sure to use an air purifier. Always wear a mask.

## Double-Check Before Soldering Components

It is easier to prevent a bad solder joint than to fix one. To correct a solder joint, apply flux to solder wick and press it against the joint with the iron, or apply a small amount of flux to the iron tip, melt the solder, and simultaneously press a solder sucker against it to absorb the solder.

## Apply Flux If Solder Is Not Sticking

Melt flux onto the iron tip to coat it, or use a flux pen to apply it directly to the PCB pads.

## Touch the Iron First When Starting, Remove It Last When Finishing

Place the iron on the pad first to preheat the PCB and component, then melt the solder onto the joint. When finishing, remove the solder first, then remove the iron last.

## Use Masking Tape to Temporarily Hold Components

For components like sockets, securing them with masking tape before soldering is helpful. This is especially important when you need to flip the board over, as components can be difficult to hold in place.

## Clean the Flux After Soldering

Scrub the remaining flux and any areas prone to short circuits thoroughly using a toothbrush dipped in isopropyl alcohol. You can also spray alcohol on the board, scrub with a toothbrush, and let it dry. Keyboard key inputs may work fine with residual flux, but encoders and analog inputs are more susceptible to issues caused by flux bridging.

## If Something Goes Wrong, Reflow and Clean

Problems can arise from cold joints, insufficient solder, excess solder bridging neighboring pads, or electrical interference from flux residue. In most cases, reflowing the solder joint and cleaning the flux will resolve the issue.

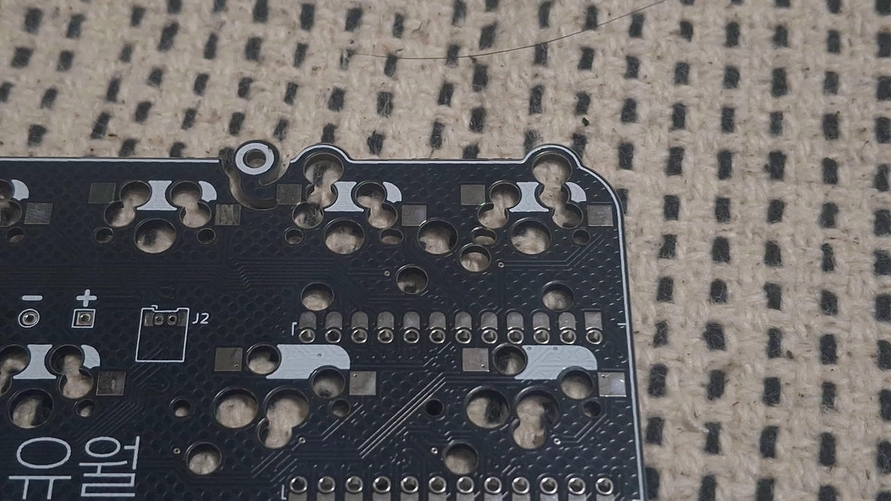
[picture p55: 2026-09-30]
images/yuwolBuildHotswap0.jpg

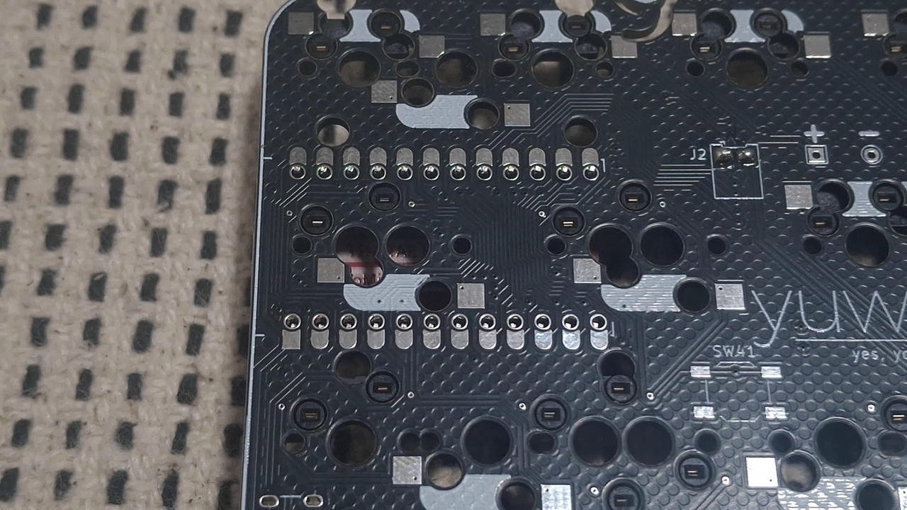
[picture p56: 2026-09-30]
images/yuwolBuildDevSolder2.jpg

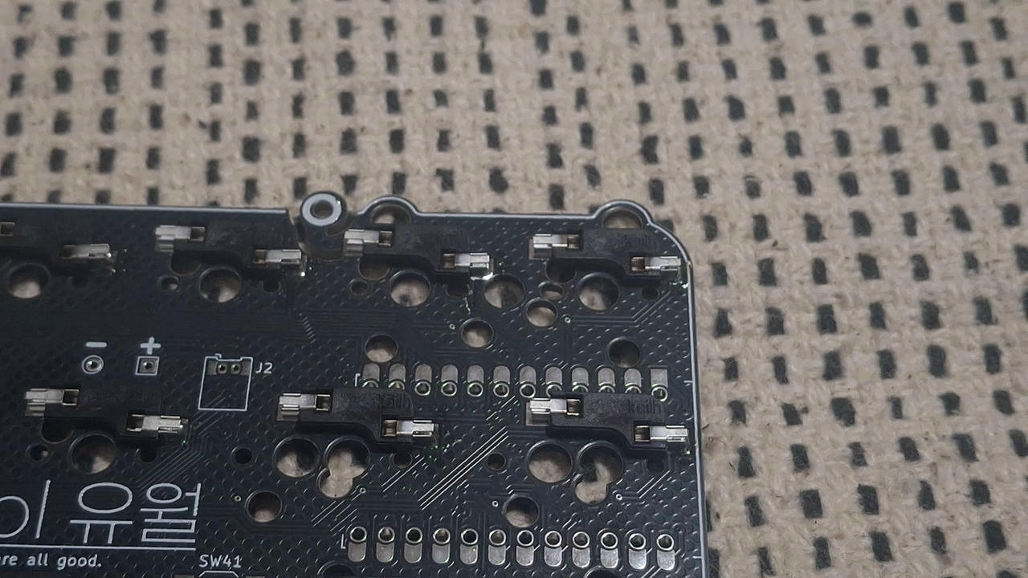
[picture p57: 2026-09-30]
images/yuwolBuildHotswap2.jpg

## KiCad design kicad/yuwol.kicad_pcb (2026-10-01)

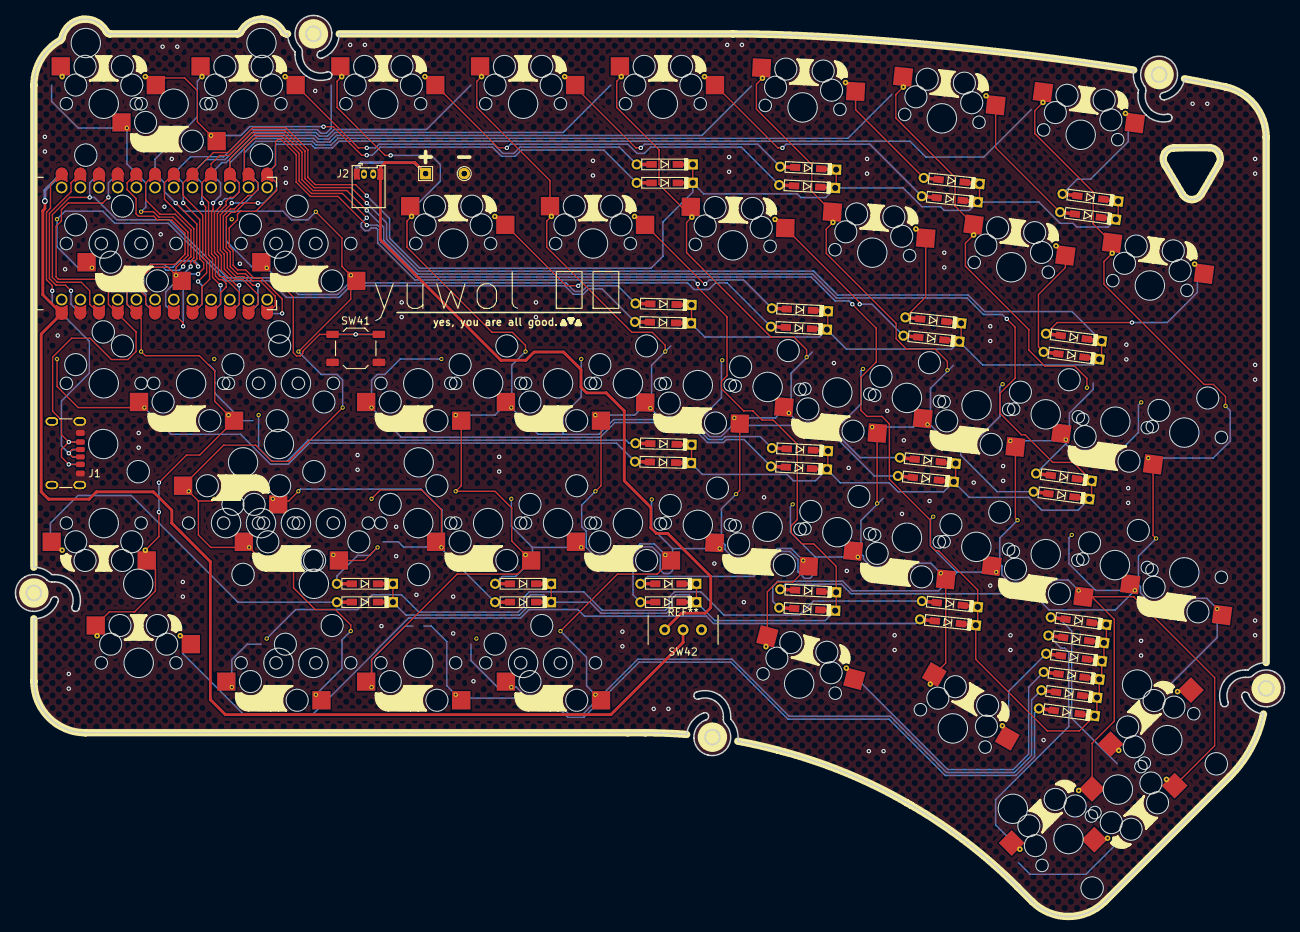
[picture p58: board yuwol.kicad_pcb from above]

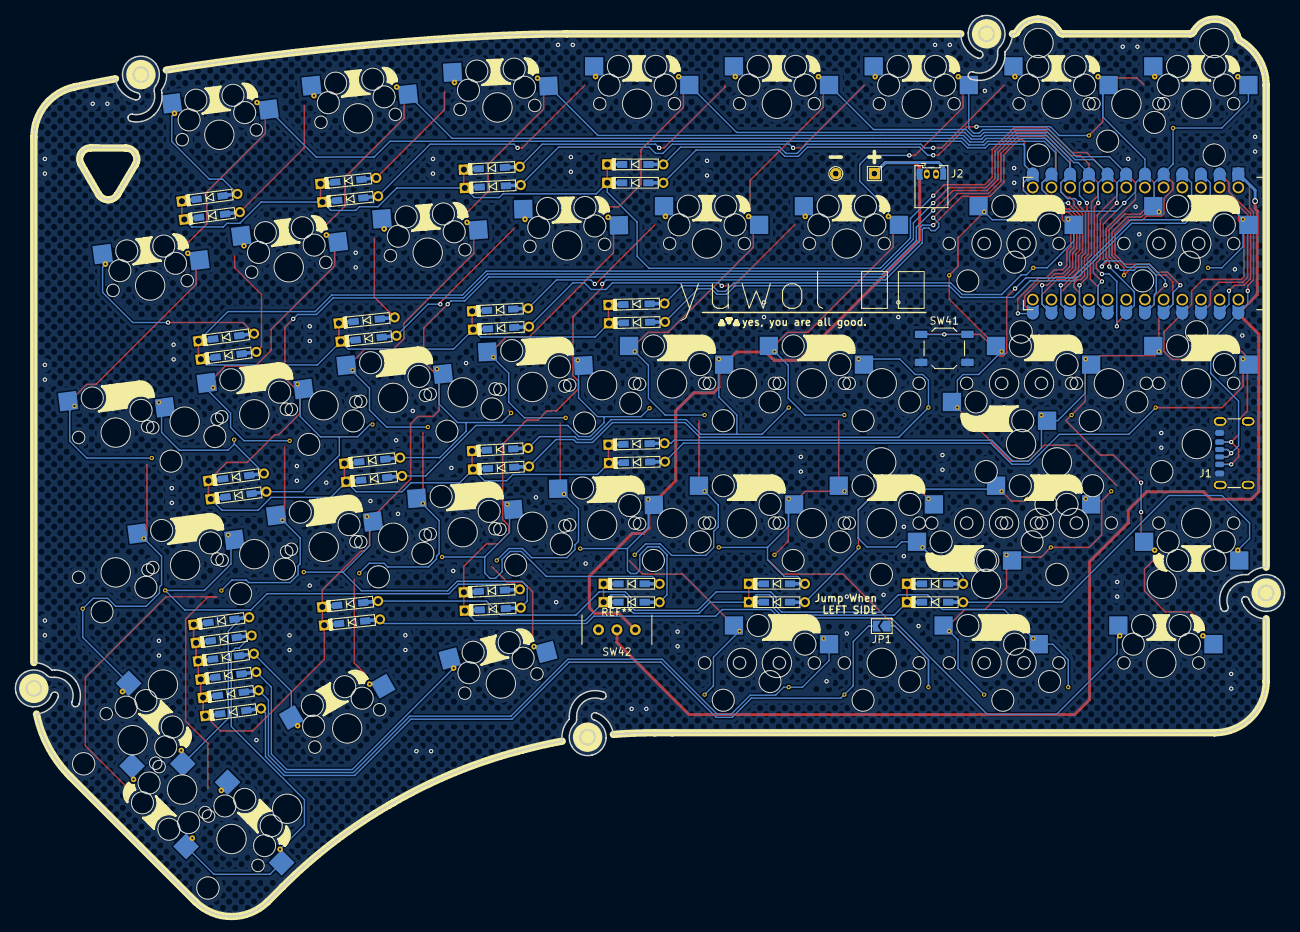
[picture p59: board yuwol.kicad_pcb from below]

Board: 2 copper layers, 172.5 x 122.5 mm, 115 parts (26 on the bottom side), 59 nets.

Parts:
D1, D2, D3, D4, D5, D6, D7, D8, D9, D10, D11, D12, D13, D14, D15, D16, D17, D18, D19, D20, D21, D22, D23, D24, D25, D26, D27, D28, D29, D30, D31, D32, D33, D34, D35, D36, D37, D38, D39, D40: D; Diode_TH_SMD_REVERSIBLE
J1, J1#2: USB_C_Receptacle_PowerOnly_6P; USB_C_Receptacle_GCT_USB4125-xx-x_6P_TopMnt_Horizontal
J2: Conn_01x02_Socket; Molex_PicoBlade_53048-0210_1x02_P1.25mm_Horizontal_Reversib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
JP1: SolderJumper_2_Open; SolderJumper-2_P1.3mm_Open_TrianglePad1.0x1.5mm
SW1, SW2, SW3, SW4, SW5, SW6, SW7, SW8, SW11, SW12, SW13, SW14, SW15, SW16, SW25, SW33, SW37, SW38, SW39: SW_Push; MX_Hotswap_FootprintPropertyFix_Guided
SW1#2, SW18#2, SW26, SW26#4: SW_Push; MX_HotswapOnesideReverse_Via_Guided
SW9, SW9#2, SW10, SW10#2, SW17, SW17#2, SW18, SW19, SW19#2, SW20, SW20#2, SW21, SW21#2, SW22, SW22#2, SW23, SW23#2, SW24, SW24#2, SW26#2, SW26#3, SW27, SW27#2, SW28, SW28#2, SW29, SW29#2, SW30, SW30#2, SW31, SW31#2, SW32, SW32#2, SW34, SW34#2, SW35, SW36, SW36#2: SW_Push; MX_HotswapOneside_Via_Guided
SW39#2, SW40: SW_Push; MX_HotswapReverse_FootprintPropertyFix_Guided
SW41, SW41#2: SW_Push; SW_SPST_TL3342
SW42: SW_SPDT; SW_SPDT_SS-12D00
TP+1, TP+1#2: TestPoint; TestPoint_THTPad_1.5x1.5mm_Drill0.7mm
TP-1, TP-1#2: TestPoint; TestPoint_THTPad_D1.5mm_Drill0.7mm
U1: ProMicro; ProMicro_ReveribleThru_ComponentUp_OuterPad

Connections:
BATT: J2.1, SW42.3 (C), TP+1.1 (1_1), TP+1#2.1
COL1: SW1.1, SW1#2.1, SW9.1, SW9#2.1, SW17.1, SW17#2.1, SW25.1, SW33.1, U1.20 (F4/A3)
COL2: SW2.1, SW10.1, SW10#2.1, SW18.1, SW18#2.1, SW26.1, SW26#2.1, SW26#3.1, SW26#4.1, SW34.1, SW34#2.1, U1.19 (F5/A2)
COL3: JP1.1 (A), SW3.1, SW11.1, SW19.1, SW19#2.1, SW27.1, SW27#2.1, SW35.2, U1.18 (F6/A1)
COL4: SW4.1, SW12.1, SW20.1, SW20#2.1, SW28.1, SW28#2.1, SW36.1, SW36#2.1, U1.17 (F7/A0)
COL5: SW5.1, SW13.1, SW21.1, SW21#2.1, SW29.1, SW29#2.1, SW37.1, U1.16 (B1/15)
COL6: SW6.1, SW14.1, SW22.1, SW22#2.1, SW30.1, SW30#2.1, SW38.1, U1.15 (B3/14)
COL7: SW7.1, SW15.1, SW23.1, SW23#2.1, SW31.1, SW31#2.1, SW39.1, SW39#2.1, U1.14 (B2/16)
COL8: SW8.1, SW16.1, SW24.1, SW24#2.1, SW32.1, SW32#2.1, SW40.1, U1.13 (B6/10)
GND: J1.A12 (GND), J1.B12 (GND), J1.SH (SHIELD), J1#2.A12, J1#2.B12, J1#2.SH, J2.2, SW41.2, SW41#2.2, TP-1.1 (1_1), TP-1#2.1, U1.3 (GND), U1.4 (GND), U1.23 (GND)
unnamed: D1.2 (A), SW1.2, SW1#2.2
unnamed: D2.2 (A), SW2.2
unnamed: D3.2 (A), SW3.2
unnamed: D4.2 (A), SW4.2
unnamed: D5.2 (A), SW5.2
unnamed: D6.2 (A), SW6.2
unnamed: D7.2 (A), SW7.2
unnamed: D8.2 (A), SW8.2
unnamed: D9.2 (A), SW9.2, SW9#2.2
unnamed: D10.2 (A), SW10.2, SW10#2.2
unnamed: D11.2 (A), SW11.2
unnamed: D12.2 (A), SW12.2
unnamed: D13.2 (A), SW13.2
unnamed: D14.2 (A), SW14.2
unnamed: D15.2 (A), SW15.2
unnamed: D16.2 (A), SW16.2
unnamed: D17.2 (A), SW17.2, SW17#2.2
unnamed: D18.2 (A), SW18.2, SW18#2.2
unnamed: D19.2 (A), SW19.2, SW19#2.2
unnamed: D20.2 (A), SW20.2, SW20#2.2
unnamed: D21.2 (A), SW21.2, SW21#2.2
unnamed: D22.2 (A), SW22.2, SW22#2.2
unnamed: D23.2 (A), SW23.2, SW23#2.2
unnamed: D24.2 (A), SW24.2, SW24#2.2
unnamed: D25.2 (A), SW25.2
unnamed: D26.2 (A), SW26.2, SW26#2.2, SW26#3.2, SW26#4.2
unnamed: D27.2 (A), SW27.2, SW27#2.2
unnamed: D28.2 (A), SW28.2, SW28#2.2
unnamed: D29.2 (A), SW29.2, SW29#2.2
unnamed: D30.2 (A), SW30.2, SW30#2.2
unnamed: D31.2 (A), SW31.2, SW31#2.2
unnamed: D32.2 (A), SW32.2, SW32#2.2
unnamed: D33.2 (A), SW33.2
unnamed: D34.2 (A), SW34.2, SW34#2.2
unnamed: D35.2 (A), JP1.2 (B), SW35.1
unnamed: D36.2 (A), SW36.2, SW36#2.2
unnamed: D37.2 (A), SW37.2
unnamed: D38.2 (A), SW38.2
unnamed: D39.2 (A), SW39.2, SW39#2.2
unnamed: D40.2 (A), SW40.2
RAW: SW42.2 (B), U1.24 (RAW)
ROW1: D1.1 (K), D2.1 (K), D3.1 (K), D4.1 (K), D5.1 (K), D6.1 (K), D7.1 (K), D8.1 (K), U1.8 (5/C6)
ROW2: D9.1 (K), D10.1 (K), D11.1 (K), D12.1 (K), D13.1 (K), D14.1 (K), D15.1 (K), D16.1 (K), U1.9 (6/D7)
ROW3: D17.1 (K), D18.1 (K), D19.1 (K), D20.1 (K), D21.1 (K), D22.1 (K), D23.1 (K), D24.1 (K), U1.10 (7/E6)
ROW4: D25.1 (K), D26.1 (K), D27.1 (K), D28.1 (K), D29.1 (K), D30.1 (K), D31.1 (K), D32.1 (K), U1.11 (8/B4)
ROW5: D33.1 (K), D34.1 (K), D35.1 (K), D36.1 (K), D37.1 (K), D38.1 (K), D39.1 (K), D40.1 (K), U1.12 (9/B5)
RST: SW41.1, SW41#2.1, U1.22 (RST)
SERIAL: J1.A5 (CC1), J1.B5 (CC2), J1#2.A5, J1#2.B5, U1.1 (TX0/D3)
VCC: J1.A9 (VBUS), J1.B9 (VBUS), J1#2.A9, J1#2.B9, U1.21 (VCC)

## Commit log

2026-09-07 add pcb
    [yuwol.3dm, yuwol.kicad_pcb, yuwol.kicad_sch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]
2026-09-11 place components
    [yuwol.kicad_pcb, yuwolPCB.dxf]
2026-09-12 fix pcb data
    [yuwol.kicad_pcb, yuwol.kicad_sch]
2026-09-13 connection and switch placement
    [yuwol.3dm, yuwol.kicad_pcb, yuwol.kicad_sch]
2026-09-14 connect u1 reversible
    [yuwol.kicad_pcb]
2026-09-15 wired-without battery
    [yuwol.kicad_pcb]
2026-09-15 really wired all without battery and ground
    [yuwol.kicad_pcb]
2026-09-17 add switch hole for plate
    [yuwolLeftPlate.dxf, yuwolPCB.dxf, yuwolRightPlate.dxf]
2026-09-17 finished pcb connection and positioning
    [yuwol.kicad_pcb, yuwol.kicad_sch, yuwolPCB.step]
2026-09-17 add triangle pattern and plates
    [yuwolPattern.3dm, yuwolPattern.dxf, yuwolPlateL.kicad_pcb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]
2026-09-17 add additional design elements
    [yuwol.kicad_pcb]
2026-09-17 add board point art
    [yuwol.kicad_pcb]
2026-09-17 add catch phrase
    [yuwolPlateL.kicad_pcb, yuwolPlateR.kicad_pcb]
2026-09-17 add gerbers of data
    [yuwol-B_Cu.gbr, yuwol-B_Mask.gbr, yuwol-B_Paste.gbr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]
2026-09-17 battery cover to two point screw
2026-09-17 add tooling hole: because of drilling layer
    [yuwolPlateL.kicad_pcb, yuwolPlateR.kicad_pcb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]
2026-09-17 change plate gerber hole to via
    [yuwolPlateL-B_Cu.gbr, yuwolPlateL-B_Mask.gbr, yuwolPlateL-B_Paste.gbr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]
2026-09-17 plate data save
    [yuwolPlateL.kicad_pcb]
2026-09-17 remove backside mask of hotswap vias
    [yuwol-B_Cu.gbr, yuwol-B_Mask.gbr, yuwol-B_Paste.gbr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]
2026-09-18 make one more hole on case - because of warping
2026-09-18 make slot for scarf seams
2026-09-18 mirror backspace position bridge joint, for more stiff suspension
    [yuwol-B_Cu.gbr, yuwol-B_Mask.gbr, yuwol-B_Paste.gbr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]
2026-09-22 wider usb-c hole - for various type of promicros
2026-09-23 polish fr4 plate design: copper plane for silkscreen
    [yuwolPlateL-B_Cu.gbr, yuwolPlateL-B_Mask.gbr, yuwolPlateL-B_Paste.gbr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]
2026-09-23 add dongle case
    [yuwolDongle.3dm]
2026-09-29 upload wired firmware (will make examples later)
2026-09-30 more big stablilizer hole on enter
    [yuwolPlateL-B_Cu.gbr, yuwolPlateL-B_Mask.gbr, yuwolPlateL-B_Paste.gbr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]
2026-09-30 change design to ground-pinned, add insert one
    [yuwolDongle.3dm]
2026-09-30 upload case output data
    [yuwolCaseWiredInsertBridgedL.stl, yuwolCaseWiredInsertBridgedR.stl, yuwolCaseWiredInsertL.stl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]
2026-10-01 add dongle guide, change dongle parts name
    [yuwolDongle.3dm, yuwolDongleBottom.stl, yuwolDongleBottom.stp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]
2026-10-01 mirrored outside leafspring of pcb - critical weakness point. must pull this
    [yuwol-B_Cu.gbr, yuwol-B_Mask.gbr, yuwol-B_Paste.gbr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]
2026-10-01 change name case to housing- remove upper case error
    [yuwolCaseWiredInsertBridgedL.stl, yuwolCaseWiredInsertBridgedR.stl, yuwolCaseWiredInsertL.stl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]
2026-10-01 change name housing to case - to deal with upper case problem
    [yuwolCaseWiredInsertBridgedL.stl, yuwolCaseWiredInsertBridgedR.stl, yuwolCaseWiredInsertL.stl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]
2026-10-02 separate plate and case data in 3mf
    [yuwolPlates.3mf, yuwolWiredInsert.3mf, yuwolWiredScrew.3mf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]
